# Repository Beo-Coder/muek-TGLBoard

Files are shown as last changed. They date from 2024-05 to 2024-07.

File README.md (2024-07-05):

# TGL Board

### 8x16 ARGB LED Board

This project is a small low profile PCB LED matrix that can be used as a name tag
or to display various text and animations and to play games.

If you have your own "programmable" version,
you can read more about programming [here](#programming)

# About
This project was initially planned as a gift for teachers after our graduation.  
It is a small and low cost LED matrix board.  
It consists of a 8x16 ARGB LED matrix, two buttons as user input and a USB-C jack for powering and programming. 
On the front and backside there are several places where custom text can be written to,
to further individualize the board.  
One of the main goals was that the whole board is visually appealing
and can be used without an enclosure to have a simpler and sleeker looking product.

The electronics consist of an RP2040 microcontroller and a 2 MB (16 Mbit) flash IC.  
You can read more about the electronic [here](#hardware)

To program the board,
you can use SWD on the Tag-Connect connector on the backside as well as on the [custom pads on the backside](#swd-interface).  
It is also possible to program the board over USB-C,
but this needs further hardware modifications (Read more about [here](#usb-c))

# Software
Currently, the software has four modes:

- Displaying text
- Showing animations
- Playing a game
- Setting the brightness

Between these modes, you can easily switch by holding down both buttons at the same time and waiting a bit.
You can choose the mode by going left or right and select it by either waiting or pressing both buttons again.

Inside the different modes, the two buttons have different meanings.
They change the text, the color of the text, the animation, or you can play the game.

## Text
The text can be individually programmed by modifying the [board_text_config.h](src/DisplayText/board_text_config.h) file.

## Animations
There are currently seven different animations:

- Fireworks
- Snake "AI"
- Conway's Game of Life
- Meteorite rain
- Smooth rainbow
- 'Hard' rainbow
- Jumping 'thing'

## Games
There are also two games, but only one is selected by default.

- Dino Game (Default)
- Tetris

To change the game, you need to modify [main.cpp](src/main.cpp).

### Controls: 
#### Dino Game: 
**Left**: *Duck*  
**Right**: *Jump*

After each game, your score and your high score is shown.

#### Tetris:
**Left**: *Moves block to the left*  
**Right**: *Moves block to the right*  
**Right while holding left**: *Rotating block*

After each game, your score and your high score is shown.  
This Tetris game was created by @StarMiner99

## Brightness control
The brightness is only saved when you switch the menu after setting the desired brightness.

# Programming
You can either use PlatformIO (Arduino Framework) or the official C/C++ SDK from Raspberry Pi.  
If you want to use the C/C++ SDK, please use the c-SDK branch.

For details on how these two differ, read [Runtime](README_runtime.md).

## Usage

You need PlatformIO to use this project.  
Arduino IDE might work too (not tested).

In the platform.ini file, there are now two build environments.
`pico_normal` and `pico_fast` you can read about the differences here [Runtime](README_runtime.md).  

For your own programming, you can use my pioMatrixOutput library.
Documentation is here [pioMatrixOutput](READMEpioMatrixOutput.md).

For your own text, you can use my library.
Documentation is here [Textcontroller](README_textController.md).

For flash usage, read here [Flash](README_flash.md).

**Important:**
If you brick your board (can't upload anything) please read [here](README_bricked.md).  

# Hardware

Schematic, layout, BOM and gerber files can be found [here](hardware).  

Each button has a 10k-ohm pull-down resistor and a 100-nF capacitor for debouncing.  

The design of the MCU section follows more or less the [hardware design guide for the RP2040](https://datasheets.raspberrypi.com/rp2040/hardware-design-with-rp2040.pdf).

Because of the design,
it was not possible to add a 100-nF capacitor to each LED, but each row of LEDs (16 each) has its own 10-uF cap
(I know it is not perfect or a replacement).  
Also,
there are multiple more capacitors to further decouple the matrix as good as possible
so that fast-changing patterns do not affect the MCU and its operations.  
This is further improved by the fact the whole MCU subsystem runs on 3.3V over a LDO and not the 5.0V that the LEDs run on. 
While testing, I haven't had any issues with noisy power lines.  
Also, when measuring with my oscilloscope and the matrix turning fully on and fully off as fast as possible, 
I couldn't measure any serious noise on the 5.0V rail nor on the 3.3V rail for the MCU.

## USB-C
Behind the USB-C jack, there are two unpopulated pads.
These pads cut the USB data signal, so that you can't program the board over USB.  
This can be useful, for example,
if you do not want that your teachers get confused when they plug it in to their pc :^)  
If you want to enable USB programming,
you need to short these two pads either with an 0402 0-ohm resistor or simply with solder bridges.  
Be aware that this is quite challenging to solder, you shouldn't destroy/desolder neighboring components.  
Maybe it is easier if you use a hotplate and 0-ohm resistors (Haven't tried it).  
If you order new boards, you can add those to be assembled too.  
The 27-ohm resistors on each USB data line necessary for the RP2040 are already assembled.

It should look something like this:
usb connections usbConnections

## SWD interface
The three unnamed pads on the backside above the UART pads are connections for SWD programming. 

Pinout:
<pre>
board outline
 |
 |          +---+            +---+           +---+
 |         /     \          /     \         /     \
 |        /       \        /       \       /       \
 |       +   RUN   +      +   SWD   +     +  SWCLK  +
 |        \       /        \       /       \       /
 |         \     /          \     /         \     /
 |          +---+            +---+           +---+
 |
 |                  +---+            +---+          
 |                 /     \          /     \ 
 |                /       \        /       \
 |               +   Tx    +      +   Rx    +
 |                \       /        \       /       
 |                 \     /          \     /   
 |                  +---+            +---+
</pre>

# Stand
I also created a stand for the board.
It has three different angles: 90°, 70° and 60°.  
It has place for a name on the top side and for text on the bottom side.  
Inside the stand there are three slots for 1 cent coins (EU) to make the stand more stable.  
If you want to insert those coins, you need to stop the print mid-way and insert/glue the coins in place.  
3mf and STL files can be found [here](hardware/Stand)

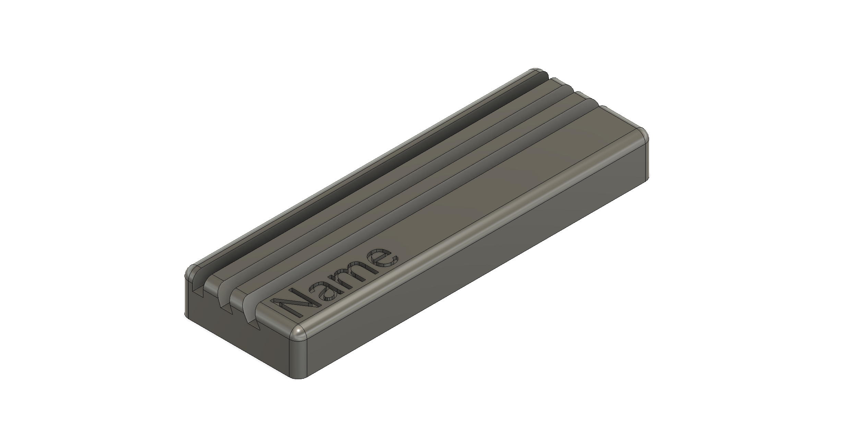
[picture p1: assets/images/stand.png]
stand


If you have any questions, please contact me.

© 2024 Leonhard Baschang

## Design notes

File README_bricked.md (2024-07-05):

If you bricked your board,
and/or you can't upload code anymore,
use a 1k ohm resistor and put it between ground (e.g. USB-C housing)
and the left side of the small smd-resistor above the flash. (See the pictures)  
While holding the resistor, plug the board back into your pc/power and the board should appear as a normal USB-stick.  
Now you can program the board again normally.  

**Be aware that if you place the resistor wrong, you could damage the board!**

This can happen, if your code does stuff that it shouldn't do like to access an array beyond its boundaries.  
Now with watchdog support, it is also possible that the watchdog somehow does not allwo you to program the board.
If you encounter some sort of watchdog related problems, you can simply disable it.

resistor placement resistorPlacement
resistor placement close resistorPlacementClose

© 2024 Leonhard Baschang

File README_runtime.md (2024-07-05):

# Runtime

## Intro
There are four different build environments:
- PlatformIO Normal
- PlatformIO Fast
- C/C++ SDK (Debug)
- C/C++ SDK (Release)

On an execution speed perspective, the C/C++ SDK release is by far the fastest.  
The fast PlatformIO environment comes seconds but is still significantly slower than the C/C++ SDK.  
The normal PlatformIO environment comes in third with sometimes near or worse performance to the fast PlatformIO environment.
The C/C++ SDK debug environment is last.

Here is a table of some measurements in the different environments

| Operation | PlatformIO Normal | PlatformIO Fast | C/C++ SDK Debug | C/C++ SDK Release |
|---|---|---|---|---|
| Creation of 1000 hamiltonian cycles | 5.472.567 | 5.313.235 | 6.995.862 | 3.246.311 |
| Calculation of 1000 Game of Life frames<br/>(without loading or displaying) | 376.821 | 368.443 | 511.537 | 149.013 |
| Calculation of 1000 Firework frames<br/>(without loading or displaying) | 920.234 | 444.682 | 431.344 | 364.977 |

All measurements are in µs.  
Note that the measurements are not 100% precise and are sometimes dependent on randomness.
But they still give a good idea of the different runtimes.

The differences can be tracked down two a few things.
The C/C++ SDK is way more optimized for the RP2040 than the Arduino (PlatformIO) framework is.
This is especially true to floating point
and divide operations
because the Arduino framework does not normally use the build in software/hardware features that the RP2040 has.  
In the PlatformIO fast environment, I added some of these features (floating point computation and hardware divider).

## Floating point computation

### Intro
The RP2040 does not have a floating-point-point(FPU), so the hardware does not support floating-point numbers.
But with a little bit of math magic, you can still calculate with floating-point numbers.
But this math magic is relatively slow and thus is not as performant as "normal" fixed-point numbers.

This math magic is "normally" done by the compiler and is done in a way so that all CPUs without an FPU can calculate this.
But luckily, Raspberry Pi developed their own piece of software which has a drastically better performance than the "normal" compiler math magic.

This piece of code is not normally used by the Arduino Framework for the RP2040.
So we need to include it ourselves.

This is why there are now two different build environments.  
`pico_normal` uses the normal algorithms from the compiler.  
`pico_fast` uses the algorithms specialized for the RP2040.  

Code wise in C/C++ there are no changes.

Note that `pico_fast` is not well tested and can crash or behave "weird".

To learn more and read about the performance increases,
see the documentation of the [C/C++ SDK section 2.7](https://datasheets.raspberrypi.com/pico/raspberry-pi-pico-c-sdk.pdf#sdk-runtime-section).

And yes, "math magic" is a real word! :^)

© 2024 Leonhard Baschang

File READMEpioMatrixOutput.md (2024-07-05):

# PIO Matrix Output Library

### Library to interface with the 8x16 ARGB Display

# Table of Contents
1. [Features](#features)
2. [Overview](#overview)
   1. [Modes](#modes)
   2. [Terminology](#terminology)
3. [Usage](#usage)
4. [Explanations](#explanations)
   1. [Framebuffer](#framebuffer)
   2. [Frame bs Subframe](#frame-vs-subframe)
   3. [RAM Usage](#ram-usage)
   4. [Output](#output)
5. [Notes](#notes)

# Features

- Framebuffer support
- Subframes support
- No CPU interaction needed during output
- Two (real) parallel outputs
- Fast refresh rate possible (~200 Hz)

# Overview
## Modes
There are two main modes of usage:
- Manual mode
- Automatic (framebuffer) mode

In Manual mode, you are responsible for creating the frames, sending the frames to the library and telling the software when to display the frames.

In Automatic (framebuffer) mode, you are only responsible for creating and sending the frames to the software.
The software will then display the frames on a fixed clock/time.
In this mode, frames are stored, as the name framebuffer implies.

## Terminology
**Frame:**
A frame is one image on the display.

**Subframes:**
One frame can be divided in subframes.
Subframes are used to create a larger range of colors and gradations.

To learn more about frames and subframes, please read [frame vs subframe](#frame-vs-subframe)

# Usage
## General use
### Initialize
`MatrixOutput ledMatrix(<pio>, <sm>, <dmaChannel>, <pin1>, <pin2>);`
- **ledMatrix**: name of the object
- **pio**: Identifier for the PIO instance (e.g. `pio0` (see examples))
- **sm**: Index of the state machine inside the PIO (e.g. `0`)
- **dmaChannel**: Index of the dma channel to use (e.g. `0`)
- **pin1**: GPIO pin of the first matrix half (e.g. `10`)
- **pin2**: GPIO pin of the second matrix half (e.g. `11`)

<br/>

### Enable Subframes
`ledMatrix.enableSubframes(<enable>);`

- **enable**: `true` or `false`. By default `true`

This command enables/disables subframes.

<br/>

### Clear Display
`ledMatrix.clearDisplay();`

Clears the display, disables subframes and the framebuffer.

<br/>

## Manual mode
### Setting display data
`ledMatrix.setDisplayData(<data>);`

- **data**: Address of an 8 by 16 Color array (see examples)

This command only sets the next frame to be sent. It does not send the data.

<br/>

### Displaying the data
`ledMatrix.sendData();`

Send the data to the display.

<br/>

## Automatic mode
### Enable Framebuffer
`ledMatrix.enableFramebuffer(<enable>);`

- **enable**: `true` or `false`. By default `true`

This command enables/disables the framebuffer.

<br/>

### Set Framebuffer interval
`ledMatrix.setFrameBufferInterval(<interval>);`

- **interval**: time in ms until the next frame is displayed (e.g. `90`)

If set to `0` the framebuffer remains on, but the timer is disabled.
You need to send the data manually.  
The interval can be set any time.

<br/>

### Load frame to framebuffer
`ledMatrix.addToFrameBuffer(<data>);`

- **data**: Address of an 8 by 16 Color array (see examples)

This command only loads the next frame to be s. It does not send the data.

<br/>

### Get free frames
`uint8_t freeFrames = ledMatrix.getFreeFrames();`

Returns the number of frames that can be added to the framebuffer before it overflows.

# Explanations
## Framebuffer
As the name suggests it buffers frames.   
Normally it is set to store up to 10 frames.
These frames can be pre-rendered by the CPU and then get output on a fixed timing/clock signal.

## Frame vs Subframe
The LEDs used in the Matrix are ARGB LEDs.
That means that each LED will remember its color.
This means that for one frame we only need to send one data frame to each LED.
So 128 dataframes in total for the whole matrix.   
So the CPU can spin around in circles until the next frame has to be sent.

Instead of waiting and spinning around (even if this is fun), the CPU could use this time to output more and more frames over and over again.  
For example, in the time the CPU waits for the next frame, there could be sent three more frames.   
And this is exactly what subframes are.  
One frame is divided in different subframe (four subframes by default).
By using the subframes in a smart way, we can create more shades of a color.
It is like PWM but fancy and more complex (not really but hey).

So if we only have frames we could only display distinct values of brightness (0,1,2, ...)
For example, we would send a `1` once to have a brightness level of 1.

But with subframes, we also can display 0.5 as a brightness level.
As described, we divide one frame into, for example, four subframes.
To display 0.5 as a continuous brightness level, we would send
`1100, 1100, 1100, 1100, ...`
over and over again. 
In this way, we can create smaller steps in brightness.
With 4 subframes, we can go in steps of 0.25.

This is, of course, a simple example, but this is what the software is doing if you enable subframes.  
You cannot directly control the values of the subframes.
Subframes are calculated and stored when setting the frame either as data or when adding the frame to the framebuffer.

## RAM usage
As you can imagine, subframes in combination with the framebuffer are really RAM intensiv.
And yes, that is true.  
Normally, we can store 10 frames in the frame buffer.
Each of these frames has four subframes.
And each subframe needs to store the color information for each of the 128 LEDs.
Each LED takes three bytes of data.  
3 x 128 = 384 bytes per subframe.  
384 x 4 = 1536 bytes per frame.  
1536 x 10 = 15360 bytes.  
That is a lot of memory.  
Especially if you remember that an Arduino UNO (R3) only has 2kB of RAM.
We use more than 7 times the amount just for the framebuffer alone.  
In total, the RP2040 has 256 kBytes of RAM.
So we have plenty to spare. (Maybe more subframes?...)

## Output
The cool thing about the RP2040 is that it has PIO.  
PIO stands for programmable IO.  
To break it down. 
It has 2 PIO Blocks with 4 State Machines each.
Each of these state machines is like a really, really, really tiny CPU.
Each machine has one input and one output buffer to get data to and from the machine.
This data can be output to the GPIO pins.
Inside these machines you can programm a small programm, to output the data just as you want.
And the output is parallel on as many pins as you want.  
To learn more about PIO,
read the [documentation of the RP2040 Chapter 3](https://datasheets.raspberrypi.com/rp2040/rp2040-datasheet.pdf#section_pio).

These state machines run independently of the CPU. 
The CPU only needs to set up the machine and handel the data in the input/output registers.

This alone is already really cool.
But it gets even better.

Even if the CPU only needs to handle the loading of the state machine register, this is still a lot of time wasted on simple tasks.   
There is a cool feature in many microcontrollers called DMA.   
DMA stands for direct memory access. 
The DMA can access memory and copy data from one place to another. 
And this extremely fast and without interaction of the CPU.
So we have an array of data in the RAM.
This data has been rendered by the CPU and stored in the RAM.
The DMA takes this data and loads it in small pieces into the state machine buffer which then outputs it onto the GPIO pins.
And all this without any interaction from the CPU.  
While the DMA and the PIO are output the data and loading the LEDs with data, the CPU can already render the next frame and/or spinning around in circles :)

# Notes
When using subframes and/or the framebuffer, please don't use the `delay` instruction.
It can mess up everything.

© 2024 Leonhard Baschang

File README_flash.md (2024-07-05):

# Flash usage
## Intro
The RP2040 does not have an internal flash.
All the flash is outside in the small black ic package on the left side over the RP2040.  
The CPUs can directly interface with this memory and execute code from it (XIP).  
The pico has some functions that let us write to this flash during runtime.  

## Usage
### Initialize
`FlashController flash;`

<br/>

### Read data
`uint8_t* data = flash.readData(<accessKey>);`

- **accessKey**: Key/ID for the data you want to access
- **data**: Start address of the data.

<br/>

### Write data
`bool status = flash.writeData(<accessKey>,<data>);`

- **accessKey**: Key/ID for the data you want to access
- **data**: The beginning of an array, where the data is stored you want to write.
- **status**: `true` if successful.

Please do not call this function unnecessary often.
Please check first if the data has changed before writing.

<br/>

### Erase all data
`flash.eraseAllData();`

This command erases all data currently stored in flash (only the data which we can also write (no code))  
Only use this when you exactly know what you are doing.  
Theoretically, you should never use this function if you use this library correctly (and it has no bugs...)

<br/>

### Add a new access key
To read or write data, the flash controller needs to know where your data is stored and how big it is.
This is achieved through predefined datasets (FlashItem).  
Each dataset has an accessKey (ID) and a size (number of bytes).  
To add/remove these, you must modify flash_controller.h/.cpp.  
**Note**: An access Key must be unique.
All the number of bytes combined should not be more than 256-1 (255), or you have to increase NUMBER_OF_PAGES by 1.  
No flash item should have more than 255 bytes of size.  
No flash item should overlap between pages (you can fill space with dummy content).

## Notes
During writing and erasing, there are no IRQs allowed, and only one core is allowed to access the flash.
The IRQs are handled by the flash controller itself.
It will disable the IRQs at the beginning of a flash command and restore them at the end.  
That only one core is running is your responsibility!  
We can only store 4095 bytes of data (one sector - internal byte)

Also see flash example.

## Technical notes
Flash can only be written to in 256 byte pages.  
Flash can only be erased in 4096 byte sectors.  
Erasing a sectors sets all bits to `1`.  
Writing only sets bits to `0`.  
So you cant write on the same address multiple times or data will get lost because you can't write an `1`.  
Because every erase-cycle wears out the flash, we only erase the sector if all the pages inside have been written.  
To further protect the flash from too many erase-cycles, we use multiple flash sectors to write our data and increment every time to the next sector.  
If no empty pages are found, we erase.  
This controller currently uses five sectors of flash.
This is a size of 4096*5 (20.480) bytes.  
This gives us 80 (20.480/256) write cycles before we need to erase.  
The flash that is solders to the board has, according to spec, a minimum of 100k erase-cycles per sector.  
This gives us 8.000.000 write cycles.  
Still, you should check if your data has changed and need rewriting before writing it again.

To every page we write, we steal one byte for internal use.  
This is the first byte to each page.  
When writing, we set this byte to a specific pattern.
With this pattern, we can easily detect a full / empty page of data.

To even further decrease erase-cycles, we could divide each page in smaller pieces.  
But this functionality is an idea for the future. :^)   
( ._.)

© 2024 Leonhard Baschang

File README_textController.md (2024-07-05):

# Textcontroller Library

### Library for multiple text controllers to display different kinds of text

# Overview
There are three different kinds of controllers. 
Scroll text, static text and tiny text.  
- **Scroll text**:
  The text is as high as the matrix and scroll from right to left
  (or from left to right) and start at the beginning if it reaches the end. 
  It is basically an endless loop of the same text.
- **Static text**: The text scrolls from right to left, but when it reaches the end it scrolls back to the beginning.
- **Tiny text**: 
  Same as static text, but only on half the size of the matrix. 
  The matrix is split in an upper and lower part.
  Each part can be controlled individual.

# Usage
## General use 
### Initialize
`ScrollText textController(<matrixOutput>, <frame>);`  
`StaticText textController(<matrixOutput>, <frame>);`  
`TinyText textController(<matrixOutput>, <frame>);`
- **matrixOutput**: Address of the MatrixOutput object (see example)
- **frame**: Address of the Color frame\[8\]\[16\] object (see example)

<br/>

### Set colors (only scroll and static text)
`textController.setColor(<textColor>, <backgroundColor>);`

- **textColor**: Address of the color for the text.
- **backgroundColor**: Address of the color for the background.

<br/>

### Set colors (only tiny text)
`textController.setColor(<upperTextColor>, <lowerTextColor>, <backgroundColor>);`

- **upperTextColor**: Address of the color for the text in the upper half.
- **lowerTextColor**: Address of the color for the text in the lower half.
- **backgroundColor**: Address of the color for the background

<br/>

### Set text (All controllers)
`textController.setText(<text>);`

- **text**: Address of the text stored as `std::string`.

<br/>

### Set text individual (tiny text only)
`textController.setUpperText(<text>);`  
`textController.setLowerText(<text>);`

- **text**: Address of the text stored as `std::string`.  
Sets the text individual for the upper/lower half.

See [decoding table](#decoding-table)

<br/>

### Refresh (shift + send to matrix) (All controllers)
`textController.refresh();`

This command shifts the text one place and displays it to the matrix.
Or display the static text.

<br/>

### Create and Load frame (shift + load frame) (All controllers)
`textController.createAndLoadFrame();`

This command creates the frame and loads it in to the buffer, so that it can be send as the next frame.  
You need to send the frame manually
(`matrix.sendData()`).

<br/>

### Set left/right shift (only scroll text)
`textController.setMode(<leftShift>);`

- **leftShift**: `bool`.
  If `true` text is shifted from right to left. 
  If `false` from left to right.
  Default is `true`

<br/>

# Decoding Table

`String text = "Hello World %H";`

(input -> output(on display))

## Normal Font (scroll and static text)
### Normal letters
`A` -> `A`  
`B` -> `B`  
...  
`y` -> `y`  
`z` -> `z`  

`0` -> `0`  
...  
`9` -> `9`

*space* -> *space* (5 pixel)    

`(` -> `(`  
`)` -> `)`  
`[` -> `[`  
`]` -> `]`  
`{` -> `{`  
`}` -> `}`  
`<` -> `<`  
`>` -> `>`

`.` -> `.`  
`,` -> `,`  
`_` -> `_`  
`-` -> `-`  

`?` -> `?`  
`!` -> `!`  
`:` -> `:`  
`;` -> `;`

### Special character (with `%` in front (`%A` -> `Ä`))

`A` -> `Ä`  
`a` -> `ä`  
...  
`ü` -> `ü`  

`1` -> *space* (1 pixel)  
`2` -> *space* (2 pixel)  
`3` -> *space* (3 pixel)  
`4` -> *space* (4 pixel)  

`l` -> *vertical line* (1 pixel)  
`|` -> *vertical line* (1 pixel) (same as l)  

`(` -> `(` (another design)  
`)` -> `)` (another design)  

`H` -> *Heart symbol*  
`S` -> *Smiley face*  

<br/>

## Tiny Font (tiny text)
### Normal letters
`A` -> `A`  
`B` -> `B`  
...  
`y` -> `A`  
`z` -> `Z`

There is no difference between small and capital letters.

`0` -> `0`  
...  
`9` -> `9`

*space* -> *space* (3 pixel)

`(` -> `(`  
`)` -> `)`  
`[` -> `[`  
`]` -> `]`   

`.` -> `.`  
`,` -> `,`  
`_` -> `_`  
`-` -> `-`

`?` -> `?`  
`!` -> `!`  
`:` -> `:`  
`;` -> `;`

`/` -> `/`  
`\ ` -> `\ `

### Special character (with `%` in front)

`1` -> *space* (1 pixel)  
`2` -> *space* (2 pixel)

`l` -> *vertical line* (1 pixel)  
`|` -> *vertical line* (1 pixel) (same as l)

`n` -> special char to indicate the line break if `text.setText(<text>);` is used.  
For example:
`Hello%nWorld` would become  
`Hello` (upper half)  
`World` (lower half)  

© 2024 Leonhard Baschang

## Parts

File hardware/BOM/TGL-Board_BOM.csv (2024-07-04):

Reference | Value | Footprint | LCSC
C1,C2,C5,C6,C7,C8,C9,C10,C11,C14,C16,C20,C21 | 100n | Capacitor_SMD:C_0402_1005Metric | C1525
C3,C4 | 1u | Capacitor_SMD:C_0402_1005Metric | C52923
C12,C13 | 15p | Capacitor_SMD:C_0402_1005Metric | C1548
C15,C17,C18,C22,C23,C24,C25,C26,C27,C28,C29 | 10u | Capacitor_SMD:C_0603_1608Metric | C19702
C19 | 47u | Capacitor_SMD:C_0805_2012Metric | C16780
D1,D2,D3,D4,D5,D6,D7,D8,D9,D10,D11,D12,D13,D14,D15,D16,D17,D18,D19,D20,D21,D22,D23,D24,D25,D26,D27,D28,D29,D30,D31,D32,D33,D34,D35,D36,D37,D38,D39,D40,D41,D42,D43,D44,D45,D46,D47,D48,D49,D50,D51,D52,D53,D54,D55,D56,D57,D58,D59,D60,D61,D62,D63,D64,D65,D66,D67,D68,D69,D70,D71,D72,D73,D74,D75,D76,D77,D78,D79,D80,D81,D82,D83,D84,D85,D86,D87,D88,D89,D90,D91,D92,D93,D94,D95,D96,D97,D98,D99,D100,D101,D102,D103,D104,D105,D106,D107,D108,D109,D110,D111,D112,D113,D114,D115,D116,D117,D118,D119,D120,D121,D122,D123,D124,D125,D126,D127,D128 | WS2812B | LeosLib:LED_WS2812B_XL-1615RGBC-WS2812B | C5349954
IC1 | W25Q16JVUXIQ_TR | W25Q16JVUXIQ:SON50P300X200X60-9L | C2843335
J2 | USB_C_Receptacle_USB2.0_16P | Connector_USB:USB_C_Receptacle_GCT_USB4105-xx-A_16P_TopMnt_Horizontal | C2858270
R1 | 1k | Resistor_SMD:R_0402_1005Metric | C11702
R2,R6,R7 | 10k | Resistor_SMD:R_0402_1005Metric | C25744
R3,R4 | 5.1k | Resistor_SMD:R_0402_1005Metric | C25905
R5 | 100k | Resistor_SMD:R_0402_1005Metric | C25741
R8,R9 | 27 | Resistor_SMD:R_0402_1005Metric | C25156
S1 | Button 1 | PTS526:PTS526SK15SMTR2LFS | C318884
S2 | Button 2 | PTS526:PTS526SK15SMTR2LFS | C318884
U1 | RP2040 | Package_DFN_QFN:QFN-56-1EP_7x7mm_P0.4mm_EP3.2x3.2mm | C2040
U2 | AP2112K-3.3 | Package_TO_SOT_SMD:SOT-23-5 | C51118
Y1 | ABM8G-12.000MHZ-4Y-T3 | Crystal:Crystal_SMD_3225-4Pin_3.2x2.5mm | C9002

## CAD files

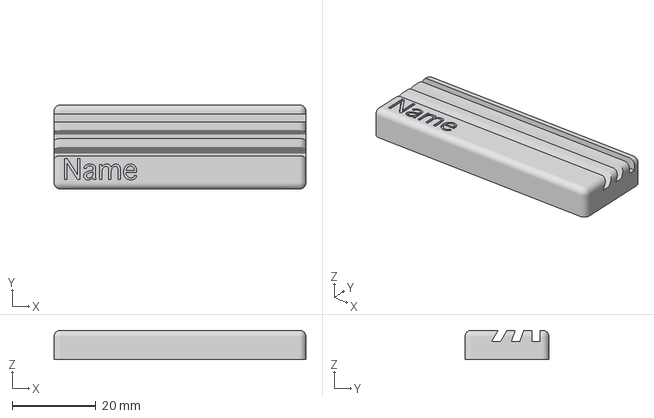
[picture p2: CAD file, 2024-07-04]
hardware/Stand/TGL-Board_Stand.3mf
60.0 x 20.0 x 7.00 mm

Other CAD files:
hardware/Stand/TGL-Board_Stand.stl

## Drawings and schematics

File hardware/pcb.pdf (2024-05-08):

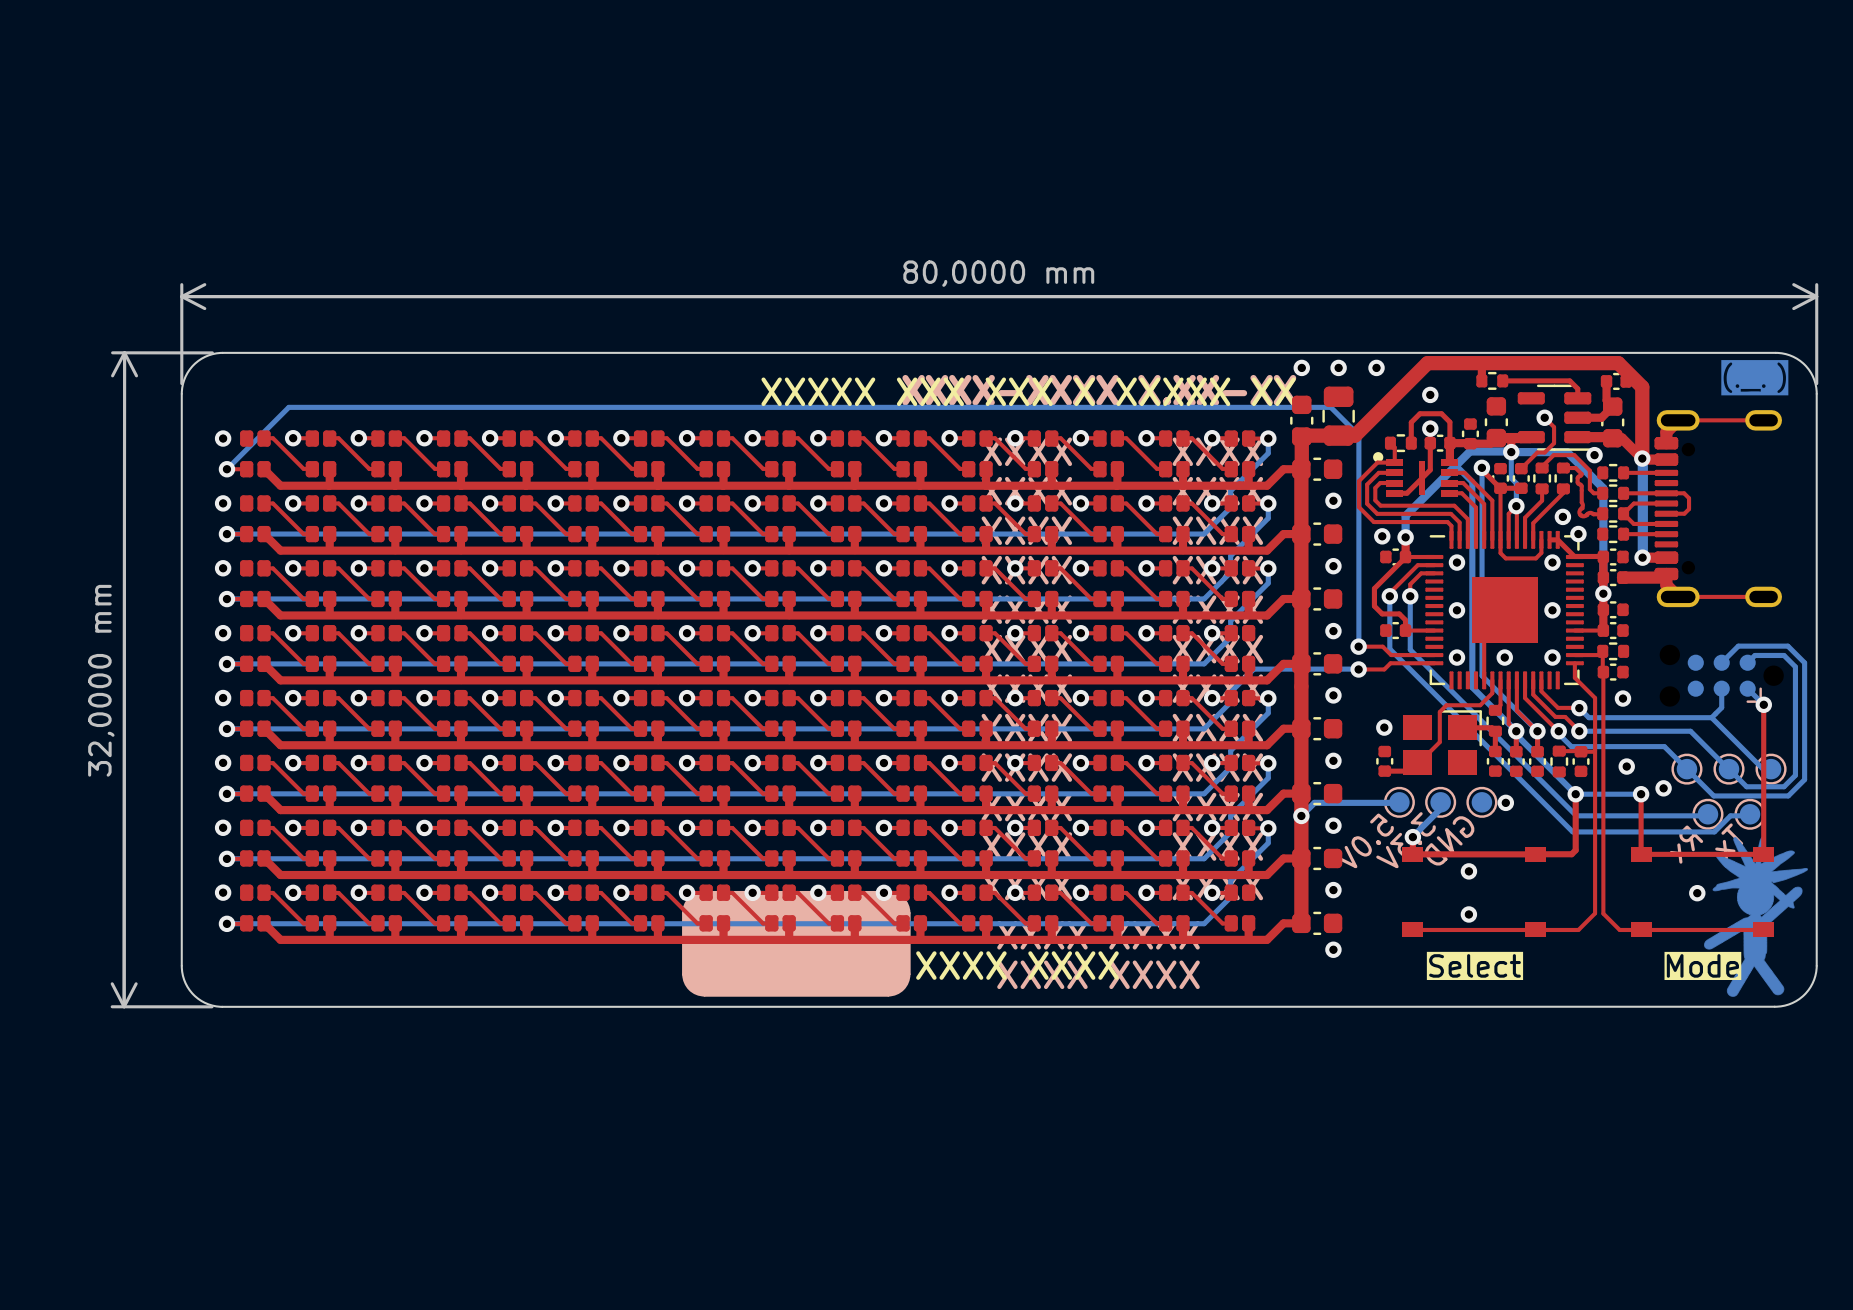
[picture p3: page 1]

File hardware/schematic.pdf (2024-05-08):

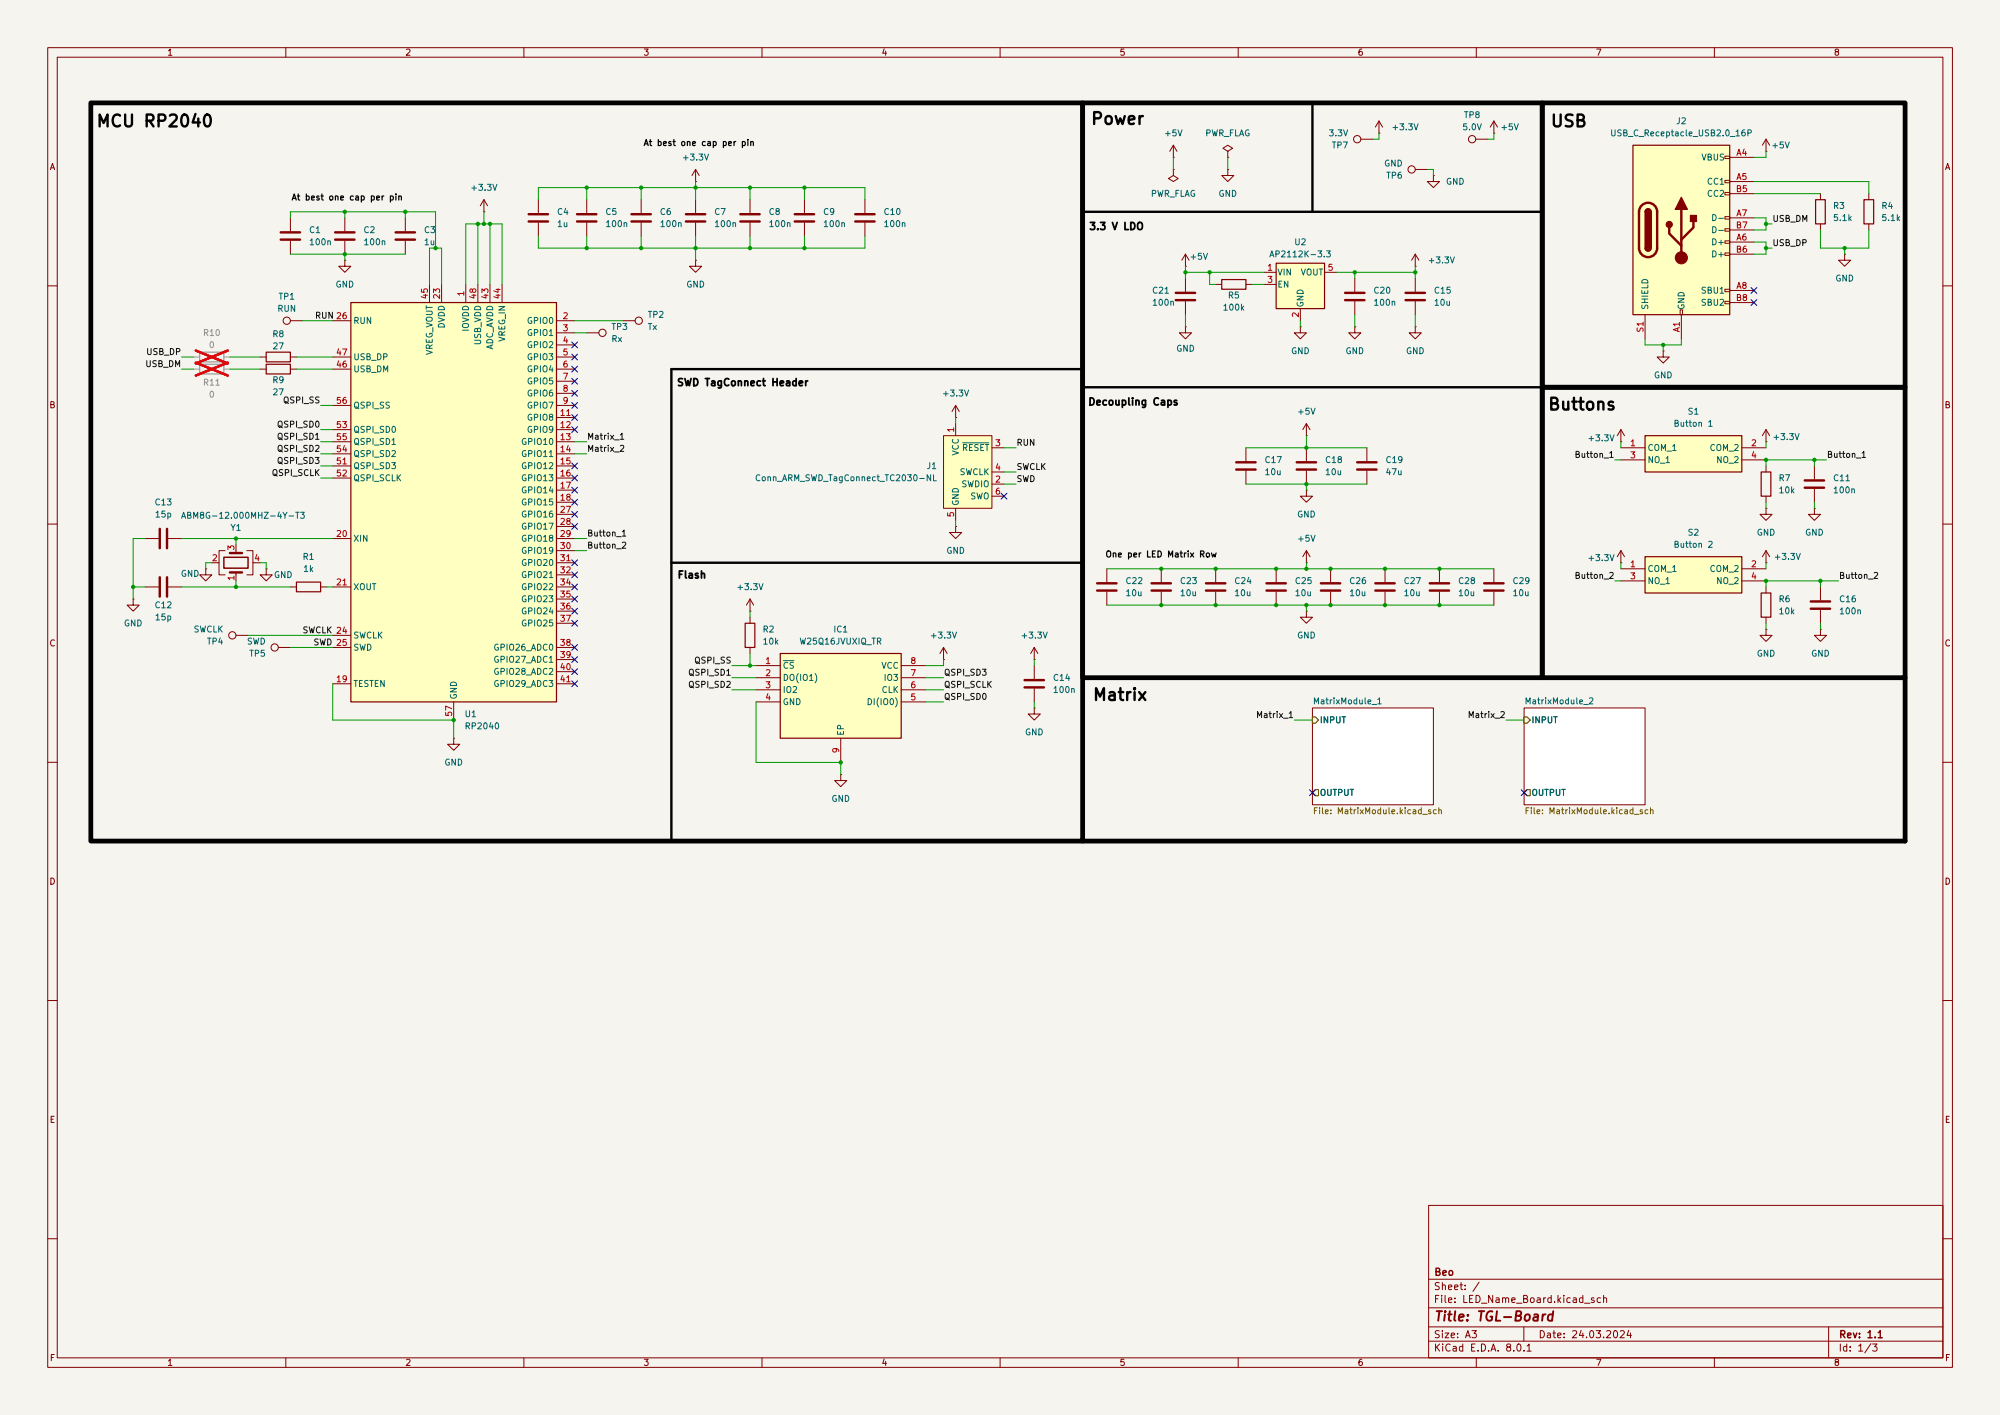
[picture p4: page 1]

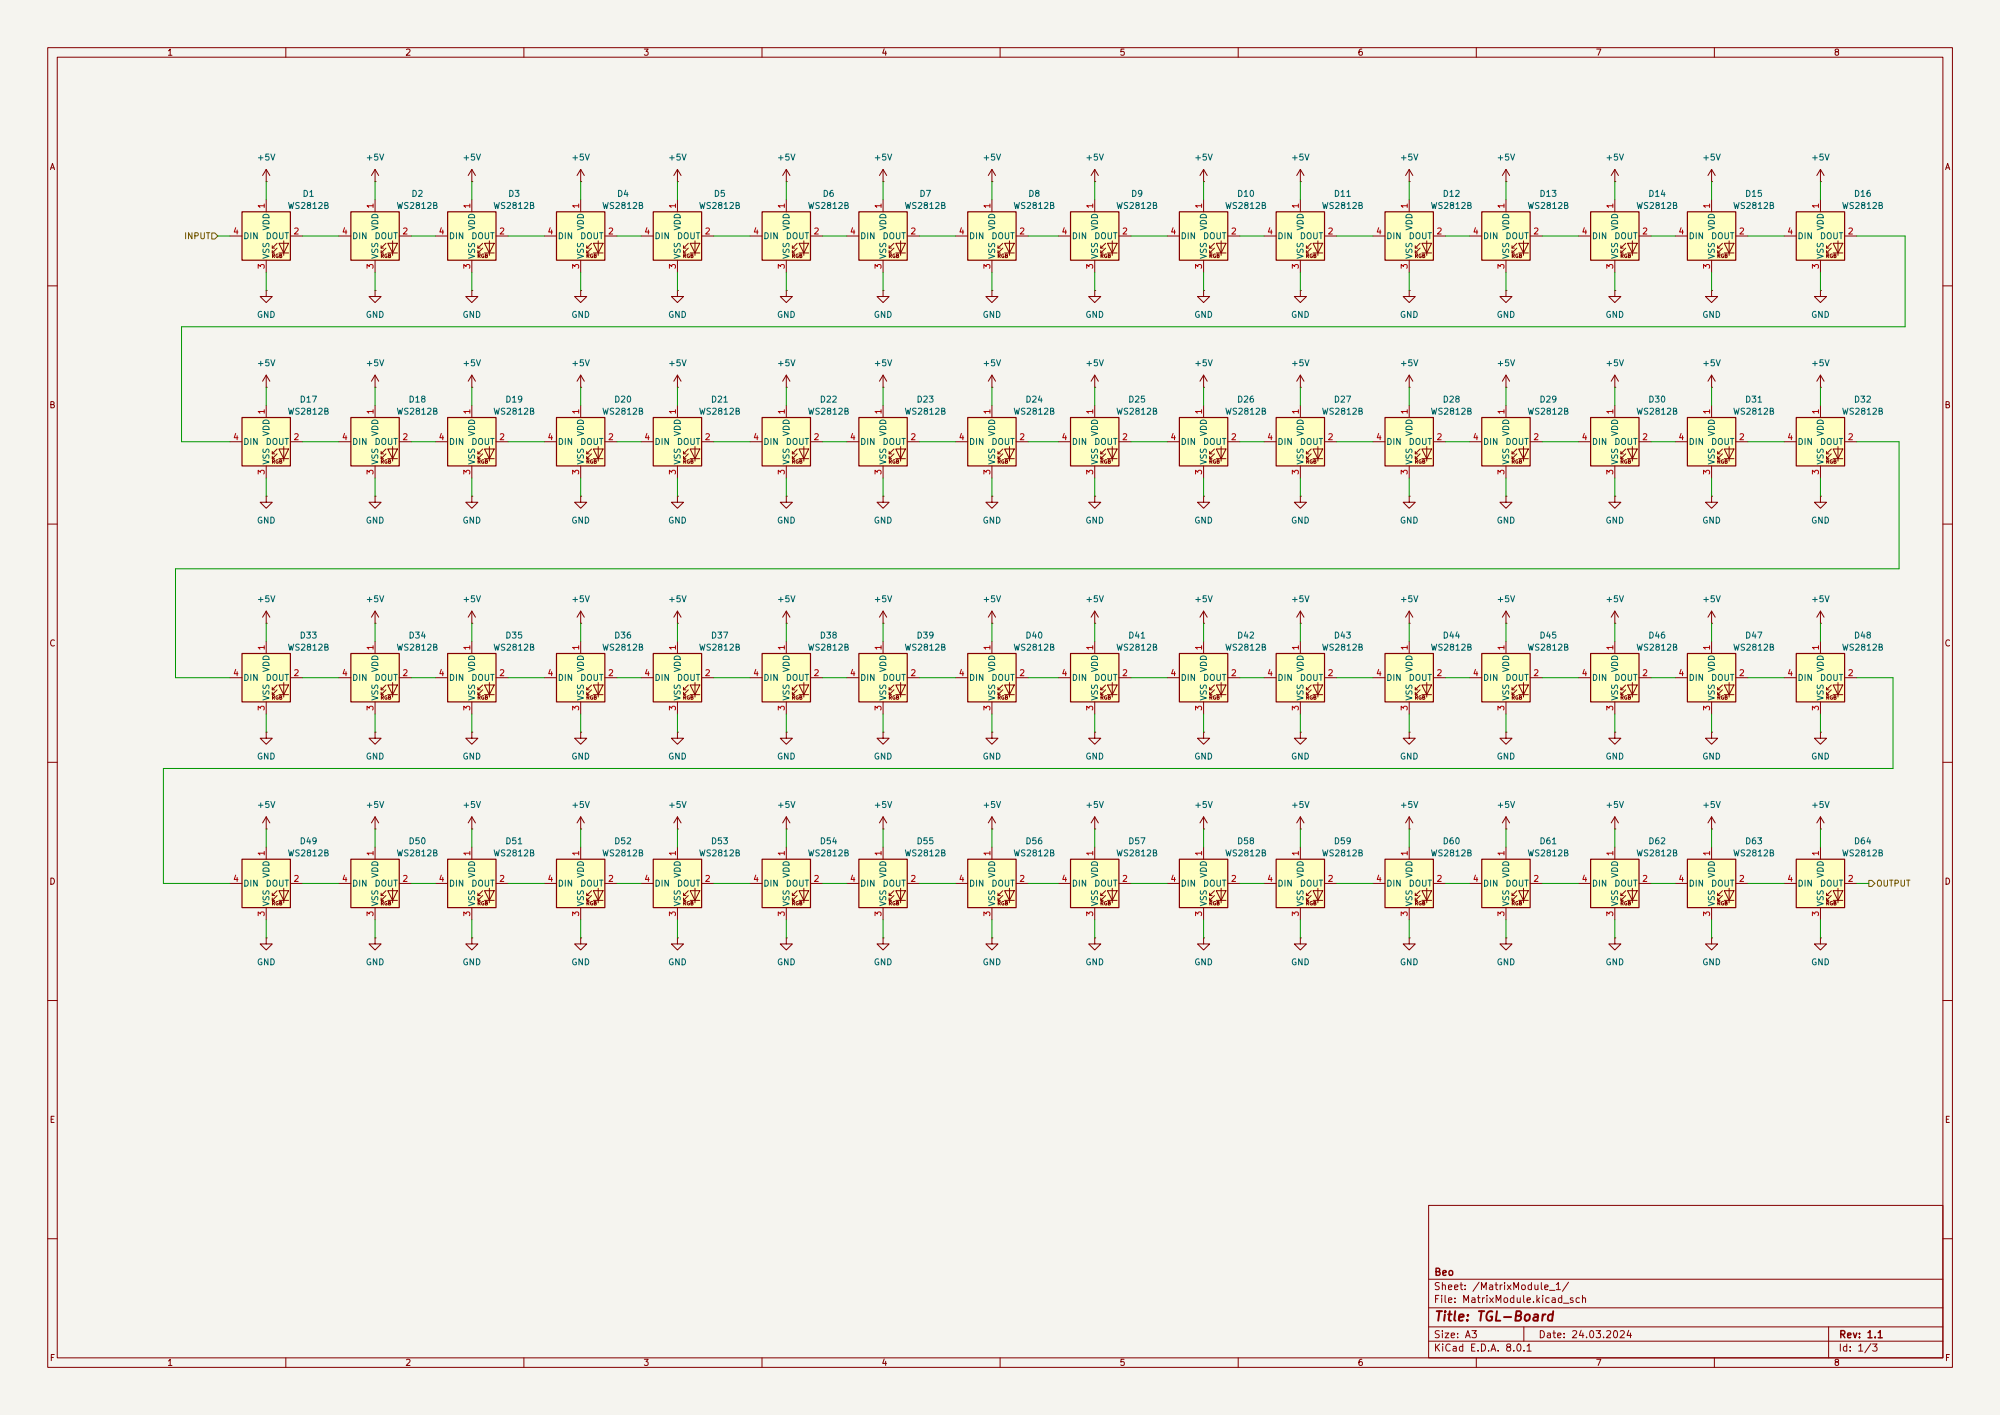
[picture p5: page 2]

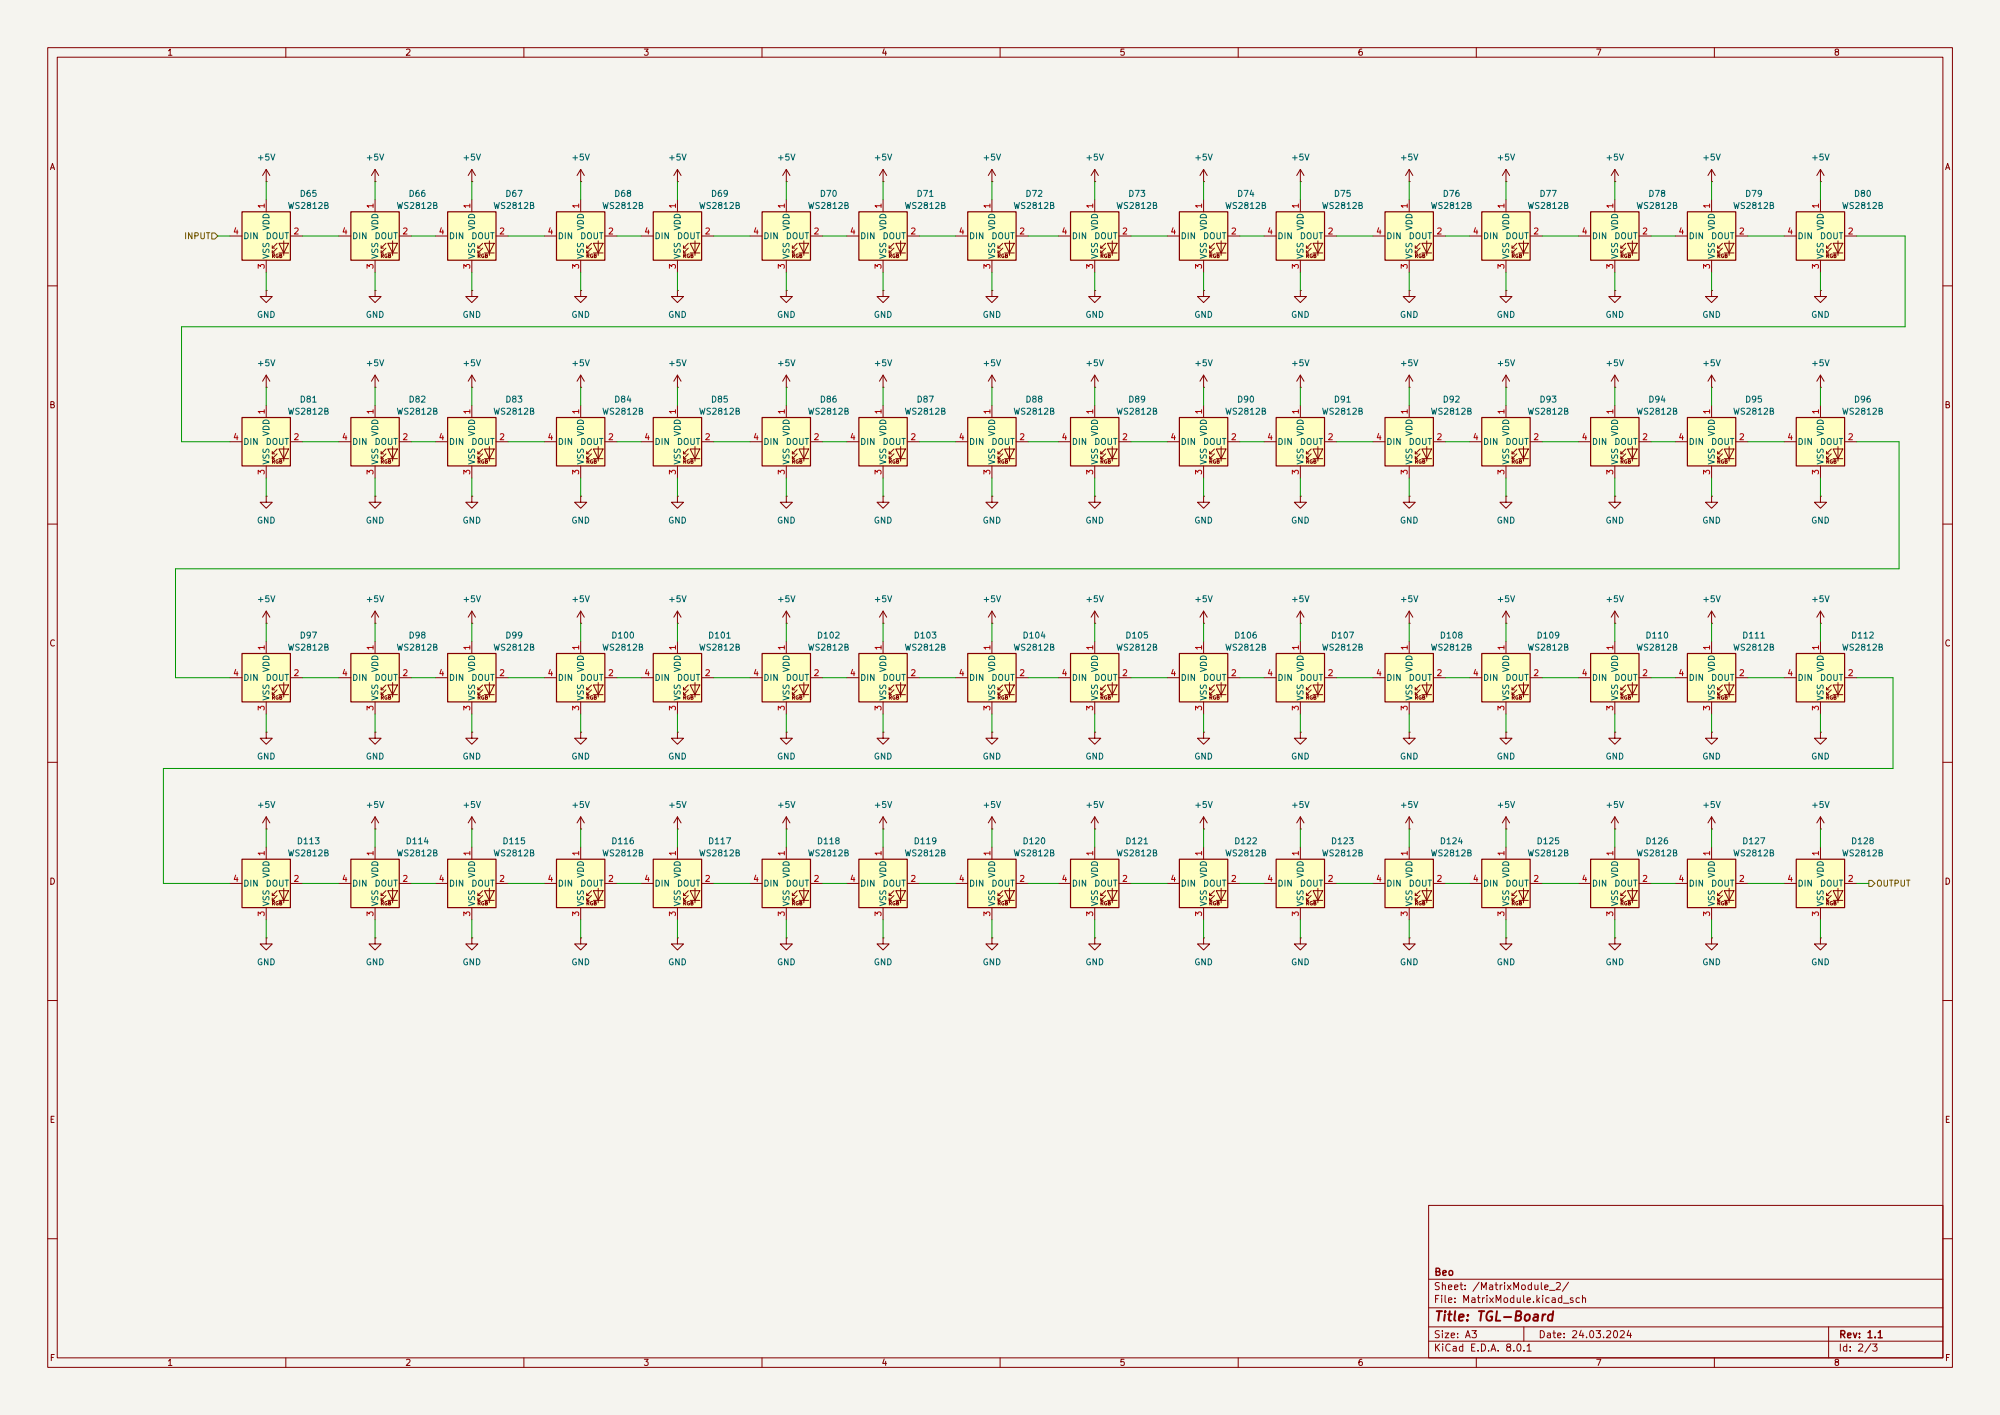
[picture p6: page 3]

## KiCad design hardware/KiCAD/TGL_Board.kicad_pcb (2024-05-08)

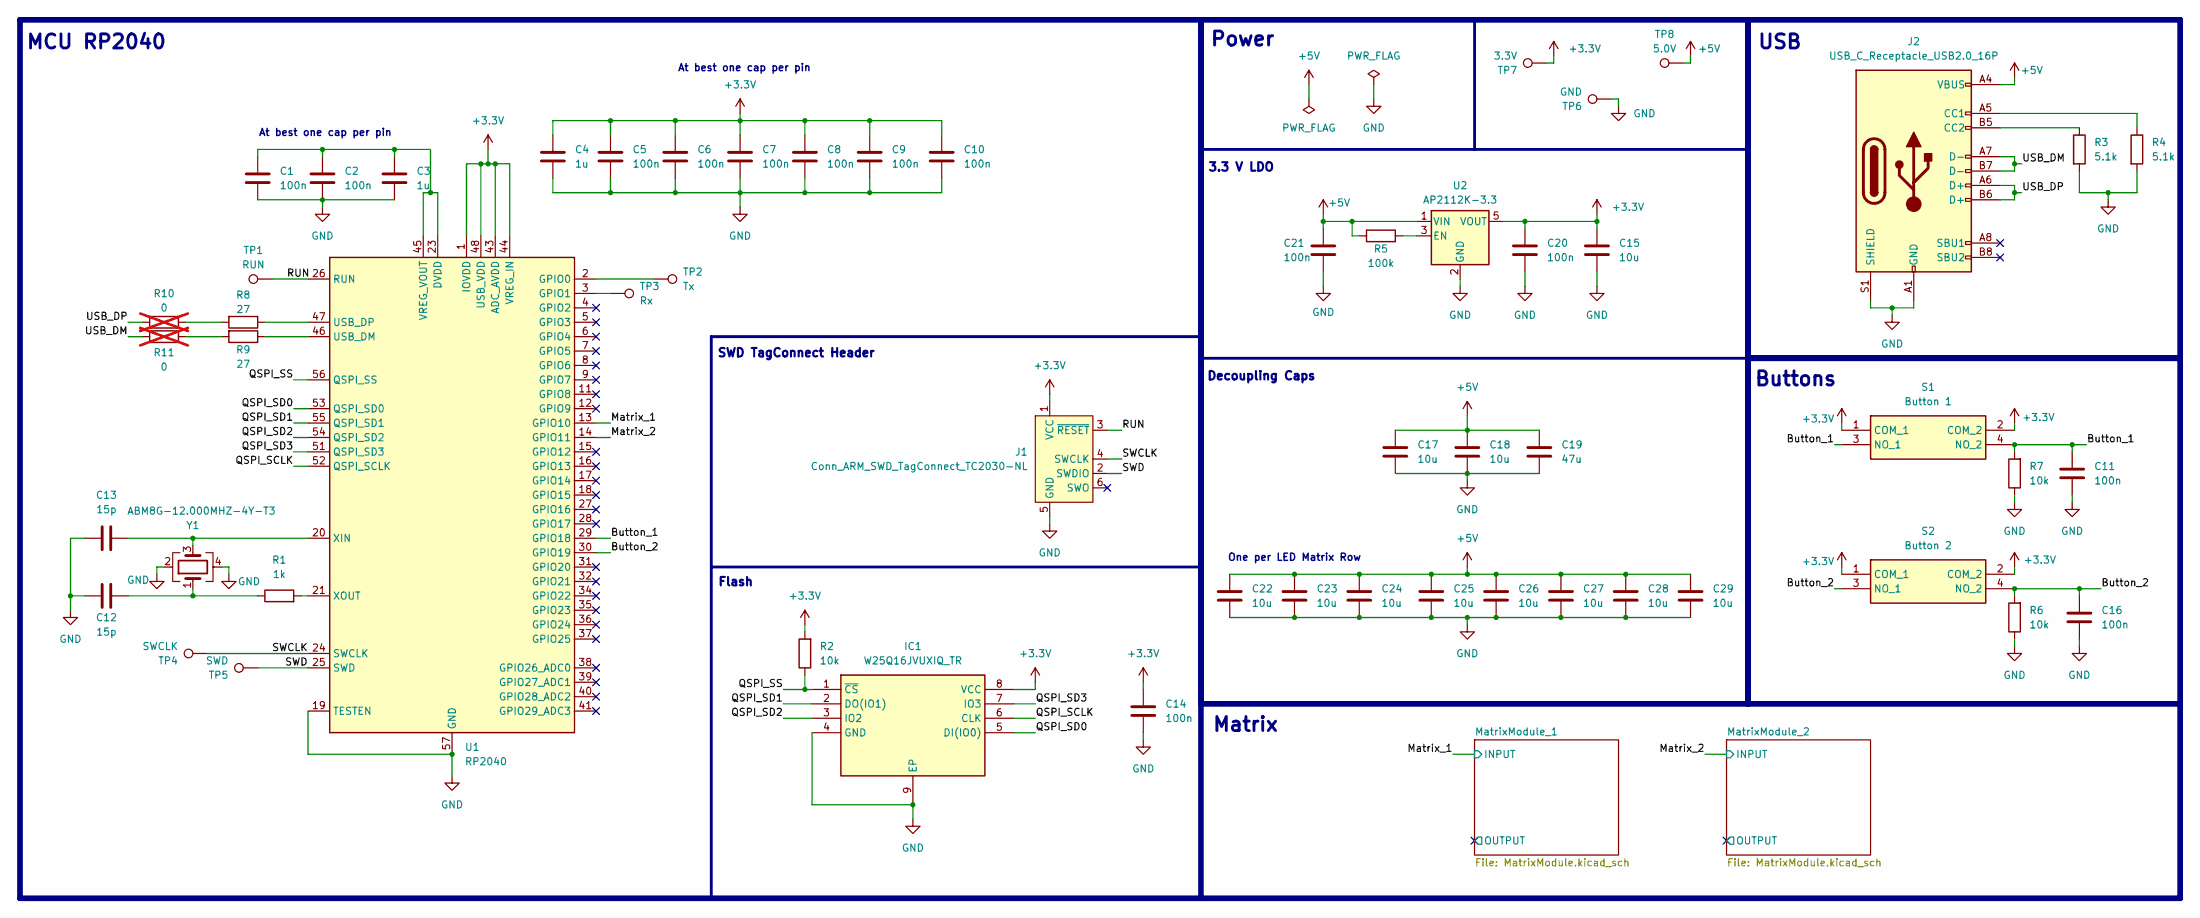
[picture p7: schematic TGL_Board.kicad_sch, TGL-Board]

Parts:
C1, C2, C5, C6, C7, C8, C9, C10, C11, C14, C16, C20, C21: 100n; C_0402_1005Metric; LCSC C1525
C3, C4: 1u; C_0402_1005Metric; LCSC C52923
C12, C13: 15p; C_0402_1005Metric; LCSC C1548
C15, C17, C18, C22, C23, C24, C25, C26, C27, C28, C29: 10u; C_0603_1608Metric; LCSC C19702
C19: 47u; C_0805_2012Metric; LCSC C16780
IC1: W25Q16JVUXIQ_TR; SON50P300X200X60-9L; Mouser Part Number 454-W25Q16JVUXIQTR
J1: Conn_ARM_SWD_TagConnect_TC2030-NL; Tag-Connect_TC2030-IDC-NL_2x03_P1.27mm_Vertical
J2: USB_C_Receptacle_USB2.0_16P; USB_C_Receptacle_GCT_USB4105-xx-A_16P_TopMnt_Horizontal; LCSC C2858270
R1: 1k; R_0402_1005Metric; LCSC C11702
R2, R6, R7: 10k; R_0402_1005Metric; LCSC C25744
R3, R4: 5.1k; R_0402_1005Metric; LCSC C25905
R5: 100k; R_0402_1005Metric; LCSC C25741
R8, R9: 27; R_0402_1005Metric; LCSC C25156
R10, R11: 0; R_0402_1005Metric; not fitted
S1: Button 1; PTS526SK15SMTR2LFS; Mouser Part Number 611-PTS526SK15SMR2L
S2: Button 2; PTS526SK15SMTR2LFS; Mouser Part Number 611-PTS526SK15SMR2L
TP1: RUN; TestPoint_Pad_D1.0mm
TP2: Tx; TestPoint_Pad_D1.0mm
TP3: Rx; TestPoint_Pad_D1.0mm
TP4: SWCLK; TestPoint_Pad_D1.0mm
TP5: SWD; TestPoint_Pad_D1.0mm
TP6: GND; TestPoint_Pad_D1.0mm
TP7: 3.3V; TestPoint_Pad_D1.0mm
TP8: 5.0V; TestPoint_Pad_D1.0mm
U1: RP2040; QFN-56-1EP_7x7mm_P0.4mm_EP3.2x3.2mm; LCSC C2040
U2: AP2112K-3.3; SOT-23-5; LCSC C51118
Y1: ABM8G-12.000MHZ-4Y-T3; Crystal_SMD_3225-4Pin_3.2x2.5mm; LCSC C9002

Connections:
+3.3V: C4.1, C5.2, C6.2, C7.2, C8.2, C9.2, C10.2, C14.1, C15.2, C20.2, IC1.8 (VCC), J1.1 (VCC), R2.2, S1.1 (COM_1), S1.2 (COM_2), S2.1 (COM_1), S2.2 (COM_2), TP7.1, U1.1 (IOVDD), U1.10 (IOVDD), U1.22 (IOVDD), U1.33 (IOVDD), U1.42 (IOVDD), U1.43 (ADC_AVDD), U1.44 (VREG_IN), U1.48 (USB_VDD), U1.49 (IOVDD), U2.5 (VOUT)
+5V: C17.2, C18.2, C19.2, C21.1, C22.2, C23.2, C24.2, C25.2, C26.2, C27.2, C28.2, C29.2, J2.A4 (VBUS), J2.A9 (VBUS), J2.B4 (VBUS), J2.B9 (VBUS), R5.1, TP8.1, U2.1 (VIN); also elsewhere on the board
/Button_1: C11.2, R7.2, S1.3 (NO_1), S1.4 (NO_2), U1.29 (GPIO18)
/Button_2: C16.2, R6.2, S2.3 (NO_1), S2.4 (NO_2), U1.30 (GPIO19)
/Matrix_1: U1.13 (GPIO10); also elsewhere on the board
/Matrix_2: U1.14 (GPIO11); also elsewhere on the board
/QSPI_SCLK: IC1.6 (CLK), U1.52 (QSPI_SCLK)
/QSPI_SD0: IC1.5 (DI(IO0)), U1.53 (QSPI_SD0)
/QSPI_SD1: IC1.2 (DO(IO1)), U1.55 (QSPI_SD1)
/QSPI_SD2: IC1.3 (IO2), U1.54 (QSPI_SD2)
/QSPI_SD3: IC1.7 (IO3), U1.51 (QSPI_SD3)
/QSPI_SS: IC1.1 (~CS), R2.1, U1.56 (QSPI_SS)
/RUN: J1.3 (~RESET), TP1.1, U1.26 (RUN)
/SWCLK: J1.4 (SWCLK), TP4.1, U1.24 (SWCLK)
/SWD: J1.2 (SWDIO), TP5.1, U1.25 (SWD)
/USB_DM: J2.A7 (D-), J2.B7 (D-), R11.2
/USB_DP: J2.A6 (D+), J2.B6 (D+), R10.2
GND: C1.1, C2.1, C3.1, C4.2, C5.1, C6.1, C7.1, C8.1, C9.1, C10.1, C11.1, C12.2, C13.2, C14.2, C15.1, C16.1, C17.1, C18.1, C19.1, C20.1, C21.2, C22.1, C23.1, C24.1, C25.1, C26.1, C27.1, C28.1, C29.1, IC1.4 (GND), IC1.9 (EP), J1.5 (GND), J2.A1 (GND), J2.A12 (GND), J2.B1 (GND), J2.B12 (GND), J2.S1 (SHIELD), R3.2, R4.2, R6.1, R7.1, TP6.1, U1.19 (TESTEN), U1.57 (GND), U2.2 (GND), Y1.2, Y1.4; also elsewhere on the board
unnamed: C12.1, R1.1, Y1.1
unnamed: J2.A5 (CC1), R4.1
unnamed: J2.B5 (CC2), R3.1
unnamed: R8.2, R10.1
unnamed: R9.2, R11.1
unnamed: TP2.1, U1.2 (GPIO0)
unnamed: TP3.1, U1.3 (GPIO1)
unnamed: R9.1, U1.46 (USB_DM)
unnamed: R8.1, U1.47 (USB_DP)
unnamed: C1.2, C2.2, C3.2, U1.23 (DVDD), U1.45 (VREG_VOUT), U1.50 (DVDD)
unnamed: C13.1, U1.20 (XIN), Y1.3
unnamed: R1.2, U1.21 (XOUT)
unnamed: R5.2, U2.3 (EN)

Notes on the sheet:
3.3 V LDO
USB
Matrix
At best one cap per pin
One per LED Matrix Row
Power
Flash
MCU RP2040
Decoupling Caps
SWD TagConnect Header
Buttons

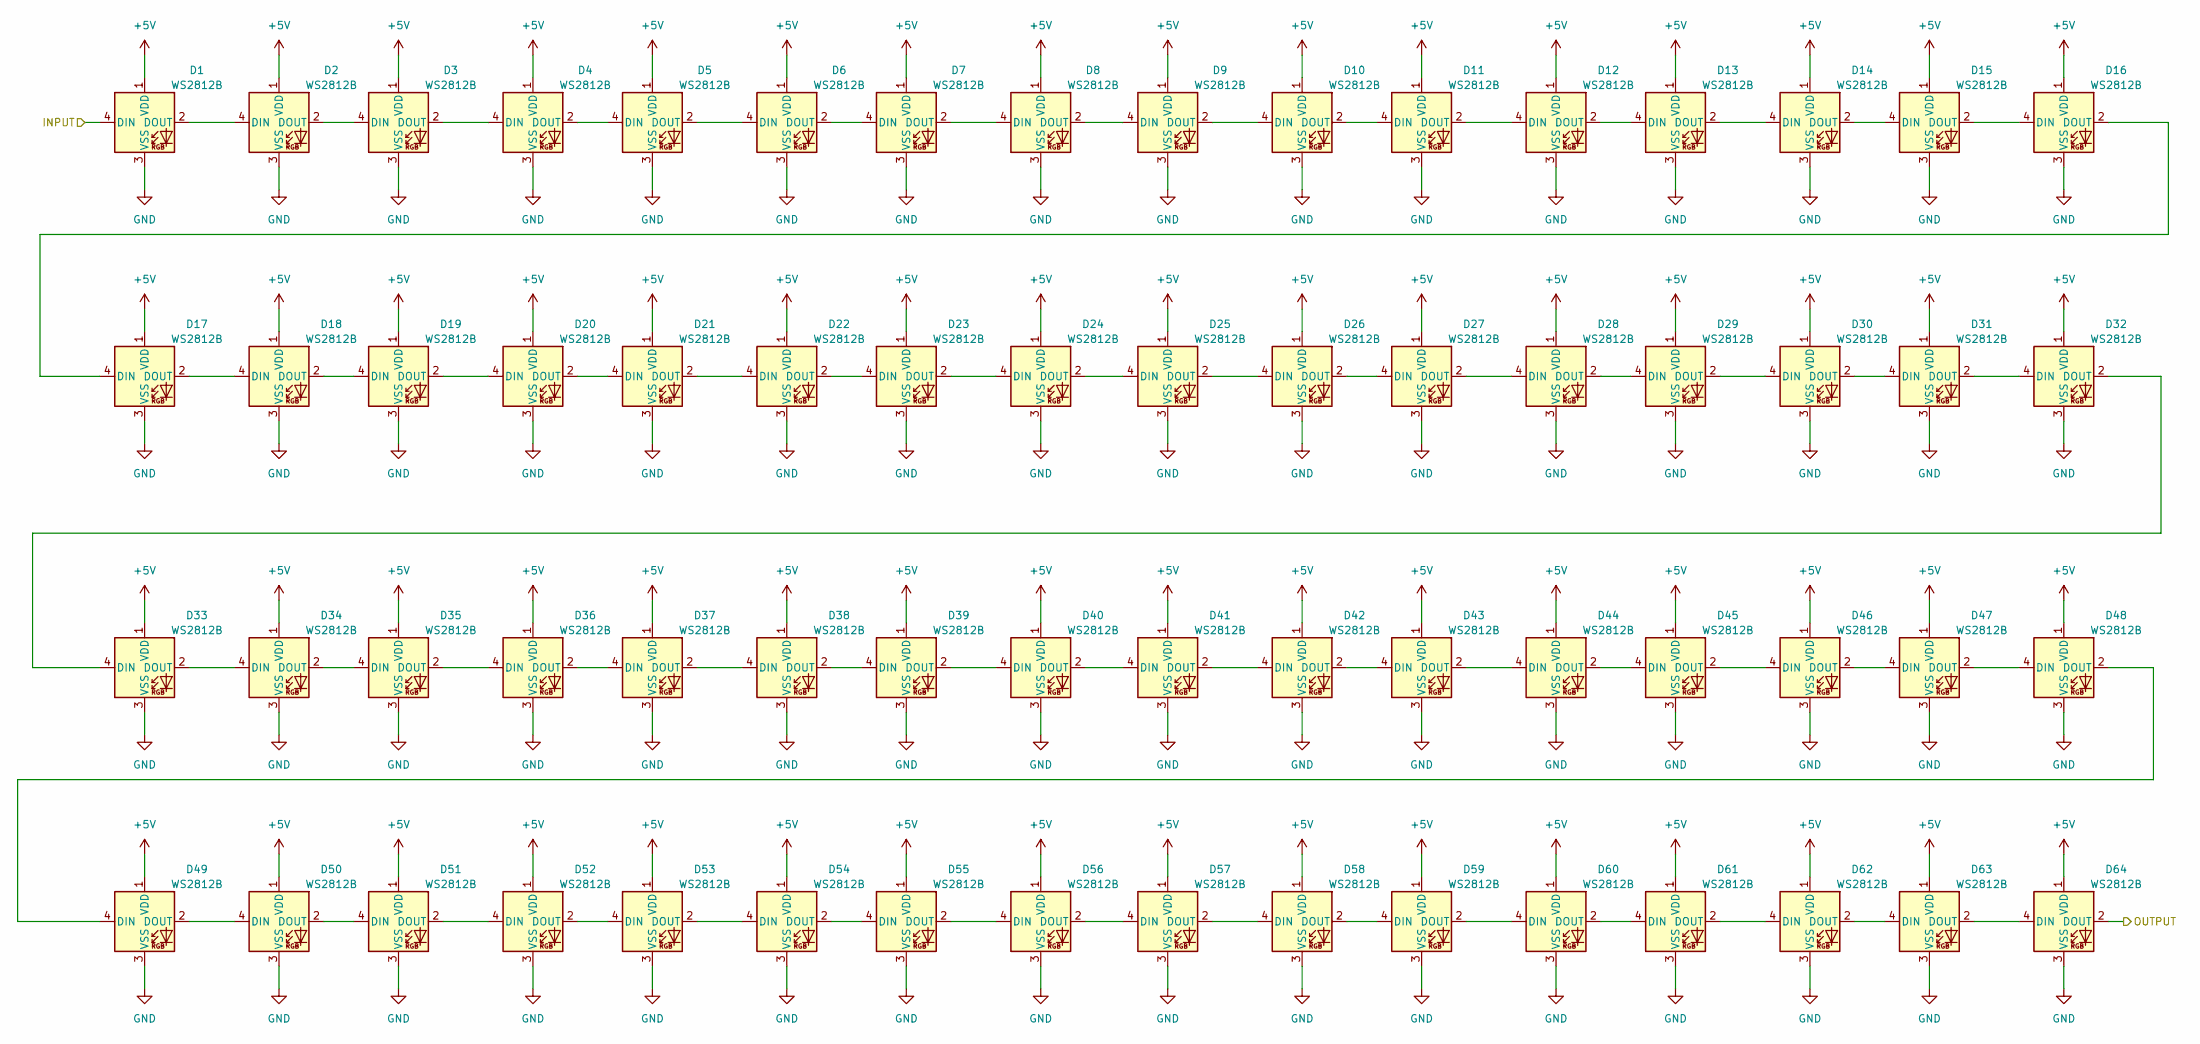
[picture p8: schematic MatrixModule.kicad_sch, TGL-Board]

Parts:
D1, D2, D3, D4, D5, D6, D7, D8, D9, D10, D11, D12, D13, D14, D15, D16, D17, D18, D19, D20, D21, D22, D23, D24, D25, D26, D27, D28, D29, D30, D31, D32, D33, D34, D35, D36, D37, D38, D39, D40, D41, D42, D43, D44, D45, D46, D47, D48, D49, D50, D51, D52, D53, D54, D55, D56, D57, D58, D59, D60, D61, D62, D63, D64: WS2812B; LED_WS2812B_XL-1615RGBC-WS2812B; LCSC C5349954

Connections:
+5V: D1.1 (VDD), D2.1 (VDD), D3.1 (VDD), D4.1 (VDD), D5.1 (VDD), D6.1 (VDD), D7.1 (VDD), D8.1 (VDD), D9.1 (VDD), D10.1 (VDD), D11.1 (VDD), D12.1 (VDD), D13.1 (VDD), D14.1 (VDD), D15.1 (VDD), D16.1 (VDD), D17.1 (VDD), D18.1 (VDD), D19.1 (VDD), D20.1 (VDD), D21.1 (VDD), D22.1 (VDD), D23.1 (VDD), D24.1 (VDD), D25.1 (VDD), D26.1 (VDD), D27.1 (VDD), D28.1 (VDD), D29.1 (VDD), D30.1 (VDD), D31.1 (VDD), D32.1 (VDD), D33.1 (VDD), D34.1 (VDD), D35.1 (VDD), D36.1 (VDD), D37.1 (VDD), D38.1 (VDD), D39.1 (VDD), D40.1 (VDD), D41.1 (VDD), D42.1 (VDD), D43.1 (VDD), D44.1 (VDD), D45.1 (VDD), D46.1 (VDD), D47.1 (VDD), D48.1 (VDD), D49.1 (VDD), D50.1 (VDD), D51.1 (VDD), D52.1 (VDD), D53.1 (VDD), D54.1 (VDD), D55.1 (VDD), D56.1 (VDD), D57.1 (VDD), D58.1 (VDD), D59.1 (VDD), D60.1 (VDD), D61.1 (VDD), D62.1 (VDD), D63.1 (VDD), D64.1 (VDD); also elsewhere on the board
/MatrixModule_1/OUTPUT: D64.2 (DOUT)
/Matrix_1: D1.4 (DIN); also elsewhere on the board
GND: D1.3 (VSS), D2.3 (VSS), D3.3 (VSS), D4.3 (VSS), D5.3 (VSS), D6.3 (VSS), D7.3 (VSS), D8.3 (VSS), D9.3 (VSS), D10.3 (VSS), D11.3 (VSS), D12.3 (VSS), D13.3 (VSS), D14.3 (VSS), D15.3 (VSS), D16.3 (VSS), D17.3 (VSS), D18.3 (VSS), D19.3 (VSS), D20.3 (VSS), D21.3 (VSS), D22.3 (VSS), D23.3 (VSS), D24.3 (VSS), D25.3 (VSS), D26.3 (VSS), D27.3 (VSS), D28.3 (VSS), D29.3 (VSS), D30.3 (VSS), D31.3 (VSS), D32.3 (VSS), D33.3 (VSS), D34.3 (VSS), D35.3 (VSS), D36.3 (VSS), D37.3 (VSS), D38.3 (VSS), D39.3 (VSS), D40.3 (VSS), D41.3 (VSS), D42.3 (VSS), D43.3 (VSS), D44.3 (VSS), D45.3 (VSS), D46.3 (VSS), D47.3 (VSS), D48.3 (VSS), D49.3 (VSS), D50.3 (VSS), D51.3 (VSS), D52.3 (VSS), D53.3 (VSS), D54.3 (VSS), D55.3 (VSS), D56.3 (VSS), D57.3 (VSS), D58.3 (VSS), D59.3 (VSS), D60.3 (VSS), D61.3 (VSS), D62.3 (VSS), D63.3 (VSS), D64.3 (VSS); also elsewhere on the board
unnamed: D1.2 (DOUT), D2.4 (DIN)
unnamed: D2.2 (DOUT), D3.4 (DIN)
unnamed: D3.2 (DOUT), D4.4 (DIN)
unnamed: D4.2 (DOUT), D5.4 (DIN)
unnamed: D5.2 (DOUT), D6.4 (DIN)
unnamed: D6.2 (DOUT), D7.4 (DIN)
unnamed: D7.2 (DOUT), D8.4 (DIN)
unnamed: D8.2 (DOUT), D9.4 (DIN)
unnamed: D9.2 (DOUT), D10.4 (DIN)
unnamed: D10.2 (DOUT), D11.4 (DIN)
unnamed: D11.2 (DOUT), D12.4 (DIN)
unnamed: D12.2 (DOUT), D13.4 (DIN)
unnamed: D13.2 (DOUT), D14.4 (DIN)
unnamed: D14.2 (DOUT), D15.4 (DIN)
unnamed: D15.2 (DOUT), D16.4 (DIN)
unnamed: D16.2 (DOUT), D17.4 (DIN)
unnamed: D17.2 (DOUT), D18.4 (DIN)
unnamed: D18.2 (DOUT), D19.4 (DIN)
unnamed: D19.2 (DOUT), D20.4 (DIN)
unnamed: D20.2 (DOUT), D21.4 (DIN)
unnamed: D21.2 (DOUT), D22.4 (DIN)
unnamed: D22.2 (DOUT), D23.4 (DIN)
unnamed: D23.2 (DOUT), D24.4 (DIN)
unnamed: D24.2 (DOUT), D25.4 (DIN)
unnamed: D25.2 (DOUT), D26.4 (DIN)
unnamed: D26.2 (DOUT), D27.4 (DIN)
unnamed: D27.2 (DOUT), D28.4 (DIN)
unnamed: D28.2 (DOUT), D29.4 (DIN)
unnamed: D29.2 (DOUT), D30.4 (DIN)
unnamed: D30.2 (DOUT), D31.4 (DIN)
unnamed: D31.2 (DOUT), D32.4 (DIN)
unnamed: D32.2 (DOUT), D33.4 (DIN)
unnamed: D33.2 (DOUT), D34.4 (DIN)
unnamed: D34.2 (DOUT), D35.4 (DIN)
unnamed: D35.2 (DOUT), D36.4 (DIN)
unnamed: D36.2 (DOUT), D37.4 (DIN)
unnamed: D37.2 (DOUT), D38.4 (DIN)
unnamed: D38.2 (DOUT), D39.4 (DIN)
unnamed: D39.2 (DOUT), D40.4 (DIN)
unnamed: D40.2 (DOUT), D41.4 (DIN)
unnamed: D41.2 (DOUT), D42.4 (DIN)
unnamed: D42.2 (DOUT), D43.4 (DIN)
unnamed: D43.2 (DOUT), D44.4 (DIN)
unnamed: D44.2 (DOUT), D45.4 (DIN)
unnamed: D45.2 (DOUT), D46.4 (DIN)
unnamed: D46.2 (DOUT), D47.4 (DIN)
unnamed: D47.2 (DOUT), D48.4 (DIN)
unnamed: D48.2 (DOUT), D49.4 (DIN)
unnamed: D49.2 (DOUT), D50.4 (DIN)
unnamed: D50.2 (DOUT), D51.4 (DIN)
unnamed: D51.2 (DOUT), D52.4 (DIN)
unnamed: D52.2 (DOUT), D53.4 (DIN)
unnamed: D53.2 (DOUT), D54.4 (DIN)
unnamed: D54.2 (DOUT), D55.4 (DIN)
unnamed: D55.2 (DOUT), D56.4 (DIN)
unnamed: D56.2 (DOUT), D57.4 (DIN)
unnamed: D57.2 (DOUT), D58.4 (DIN)
unnamed: D58.2 (DOUT), D59.4 (DIN)
unnamed: D59.2 (DOUT), D60.4 (DIN)
unnamed: D60.2 (DOUT), D61.4 (DIN)
unnamed: D61.2 (DOUT), D62.4 (DIN)
unnamed: D62.2 (DOUT), D63.4 (DIN)
unnamed: D63.2 (DOUT), D64.4 (DIN)

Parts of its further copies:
D65, D66, D67, D68, D69, D70, D71, D72, D73, D74, D75, D76, D77, D78, D79, D80, D81, D82, D83, D84, D85, D86, D87, D88, D89, D90, D91, D92, D93, D94, D95, D96, D97, D98, D99, D100, D101, D102, D103, D104, D105, D106, D107, D108, D109, D110, D111, D112, D113, D114, D115, D116, D117, D118, D119, D120, D121, D122, D123, D124, D125, D126, D127, D128: WS2812B; LED_WS2812B_XL-1615RGBC-WS2812B; LCSC C5349954

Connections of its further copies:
+5V: D65.1 (VDD), D66.1 (VDD), D67.1 (VDD), D68.1 (VDD), D69.1 (VDD), D70.1 (VDD), D71.1 (VDD), D72.1 (VDD), D73.1 (VDD), D74.1 (VDD), D75.1 (VDD), D76.1 (VDD), D77.1 (VDD), D78.1 (VDD), D79.1 (VDD), D80.1 (VDD), D81.1 (VDD), D82.1 (VDD), D83.1 (VDD), D84.1 (VDD), D85.1 (VDD), D86.1 (VDD), D87.1 (VDD), D88.1 (VDD), D89.1 (VDD), D90.1 (VDD), D91.1 (VDD), D92.1 (VDD), D93.1 (VDD), D94.1 (VDD), D95.1 (VDD), D96.1 (VDD), D97.1 (VDD), D98.1 (VDD), D99.1 (VDD), D100.1 (VDD), D101.1 (VDD), D102.1 (VDD), D103.1 (VDD), D104.1 (VDD), D105.1 (VDD), D106.1 (VDD), D107.1 (VDD), D108.1 (VDD), D109.1 (VDD), D110.1 (VDD), D111.1 (VDD), D112.1 (VDD), D113.1 (VDD), D114.1 (VDD), D115.1 (VDD), D116.1 (VDD), D117.1 (VDD), D118.1 (VDD), D119.1 (VDD), D120.1 (VDD), D121.1 (VDD), D122.1 (VDD), D123.1 (VDD), D124.1 (VDD), D125.1 (VDD), D126.1 (VDD), D127.1 (VDD), D128.1 (VDD); also elsewhere on the board
/MatrixModule_2/OUTPUT: D128.2 (DOUT)
/Matrix_2: D65.4 (DIN); also elsewhere on the board
GND: D65.3 (VSS), D66.3 (VSS), D67.3 (VSS), D68.3 (VSS), D69.3 (VSS), D70.3 (VSS), D71.3 (VSS), D72.3 (VSS), D73.3 (VSS), D74.3 (VSS), D75.3 (VSS), D76.3 (VSS), D77.3 (VSS), D78.3 (VSS), D79.3 (VSS), D80.3 (VSS), D81.3 (VSS), D82.3 (VSS), D83.3 (VSS), D84.3 (VSS), D85.3 (VSS), D86.3 (VSS), D87.3 (VSS), D88.3 (VSS), D89.3 (VSS), D90.3 (VSS), D91.3 (VSS), D92.3 (VSS), D93.3 (VSS), D94.3 (VSS), D95.3 (VSS), D96.3 (VSS), D97.3 (VSS), D98.3 (VSS), D99.3 (VSS), D100.3 (VSS), D101.3 (VSS), D102.3 (VSS), D103.3 (VSS), D104.3 (VSS), D105.3 (VSS), D106.3 (VSS), D107.3 (VSS), D108.3 (VSS), D109.3 (VSS), D110.3 (VSS), D111.3 (VSS), D112.3 (VSS), D113.3 (VSS), D114.3 (VSS), D115.3 (VSS), D116.3 (VSS), D117.3 (VSS), D118.3 (VSS), D119.3 (VSS), D120.3 (VSS), D121.3 (VSS), D122.3 (VSS), D123.3 (VSS), D124.3 (VSS), D125.3 (VSS), D126.3 (VSS), D127.3 (VSS), D128.3 (VSS); also elsewhere on the board
unnamed: D65.2 (DOUT), D66.4 (DIN)
unnamed: D66.2 (DOUT), D67.4 (DIN)
unnamed: D67.2 (DOUT), D68.4 (DIN)
unnamed: D68.2 (DOUT), D69.4 (DIN)
unnamed: D69.2 (DOUT), D70.4 (DIN)
unnamed: D70.2 (DOUT), D71.4 (DIN)
unnamed: D71.2 (DOUT), D72.4 (DIN)
unnamed: D72.2 (DOUT), D73.4 (DIN)
unnamed: D73.2 (DOUT), D74.4 (DIN)
unnamed: D74.2 (DOUT), D75.4 (DIN)
unnamed: D75.2 (DOUT), D76.4 (DIN)
unnamed: D76.2 (DOUT), D77.4 (DIN)
unnamed: D77.2 (DOUT), D78.4 (DIN)
unnamed: D78.2 (DOUT), D79.4 (DIN)
unnamed: D79.2 (DOUT), D80.4 (DIN)
unnamed: D80.2 (DOUT), D81.4 (DIN)
unnamed: D81.2 (DOUT), D82.4 (DIN)
unnamed: D82.2 (DOUT), D83.4 (DIN)
unnamed: D83.2 (DOUT), D84.4 (DIN)
unnamed: D84.2 (DOUT), D85.4 (DIN)
unnamed: D85.2 (DOUT), D86.4 (DIN)
unnamed: D86.2 (DOUT), D87.4 (DIN)
unnamed: D87.2 (DOUT), D88.4 (DIN)
unnamed: D88.2 (DOUT), D89.4 (DIN)
unnamed: D89.2 (DOUT), D90.4 (DIN)
unnamed: D90.2 (DOUT), D91.4 (DIN)
unnamed: D91.2 (DOUT), D92.4 (DIN)
unnamed: D92.2 (DOUT), D93.4 (DIN)
unnamed: D93.2 (DOUT), D94.4 (DIN)
unnamed: D94.2 (DOUT), D95.4 (DIN)
unnamed: D95.2 (DOUT), D96.4 (DIN)
unnamed: D96.2 (DOUT), D97.4 (DIN)
unnamed: D97.2 (DOUT), D98.4 (DIN)
unnamed: D98.2 (DOUT), D99.4 (DIN)
unnamed: D99.2 (DOUT), D100.4 (DIN)
unnamed: D100.2 (DOUT), D101.4 (DIN)
unnamed: D101.2 (DOUT), D102.4 (DIN)
unnamed: D102.2 (DOUT), D103.4 (DIN)
unnamed: D103.2 (DOUT), D104.4 (DIN)
unnamed: D104.2 (DOUT), D105.4 (DIN)
unnamed: D105.2 (DOUT), D106.4 (DIN)
unnamed: D106.2 (DOUT), D107.4 (DIN)
unnamed: D107.2 (DOUT), D108.4 (DIN)
unnamed: D108.2 (DOUT), D109.4 (DIN)
unnamed: D109.2 (DOUT), D110.4 (DIN)
unnamed: D110.2 (DOUT), D111.4 (DIN)
unnamed: D111.2 (DOUT), D112.4 (DIN)
unnamed: D112.2 (DOUT), D113.4 (DIN)
unnamed: D113.2 (DOUT), D114.4 (DIN)
unnamed: D114.2 (DOUT), D115.4 (DIN)
unnamed: D115.2 (DOUT), D116.4 (DIN)
unnamed: D116.2 (DOUT), D117.4 (DIN)
unnamed: D117.2 (DOUT), D118.4 (DIN)
unnamed: D118.2 (DOUT), D119.4 (DIN)
unnamed: D119.2 (DOUT), D120.4 (DIN)
unnamed: D120.2 (DOUT), D121.4 (DIN)
unnamed: D121.2 (DOUT), D122.4 (DIN)
unnamed: D122.2 (DOUT), D123.4 (DIN)
unnamed: D123.2 (DOUT), D124.4 (DIN)
unnamed: D124.2 (DOUT), D125.4 (DIN)
unnamed: D125.2 (DOUT), D126.4 (DIN)
unnamed: D126.2 (DOUT), D127.4 (DIN)
unnamed: D127.2 (DOUT), D128.4 (DIN)

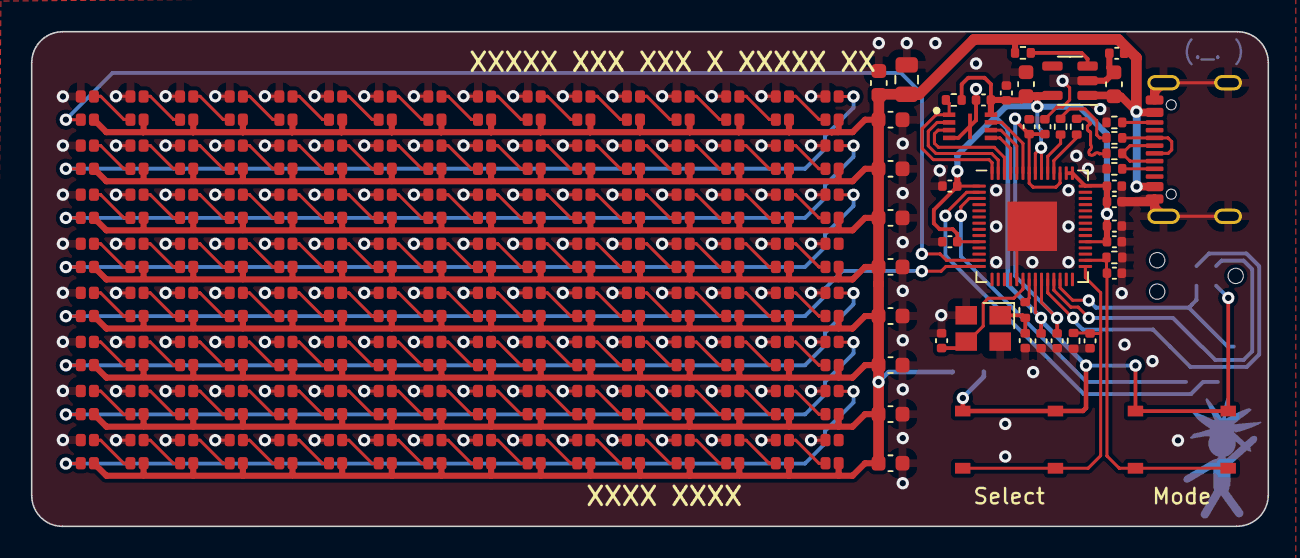
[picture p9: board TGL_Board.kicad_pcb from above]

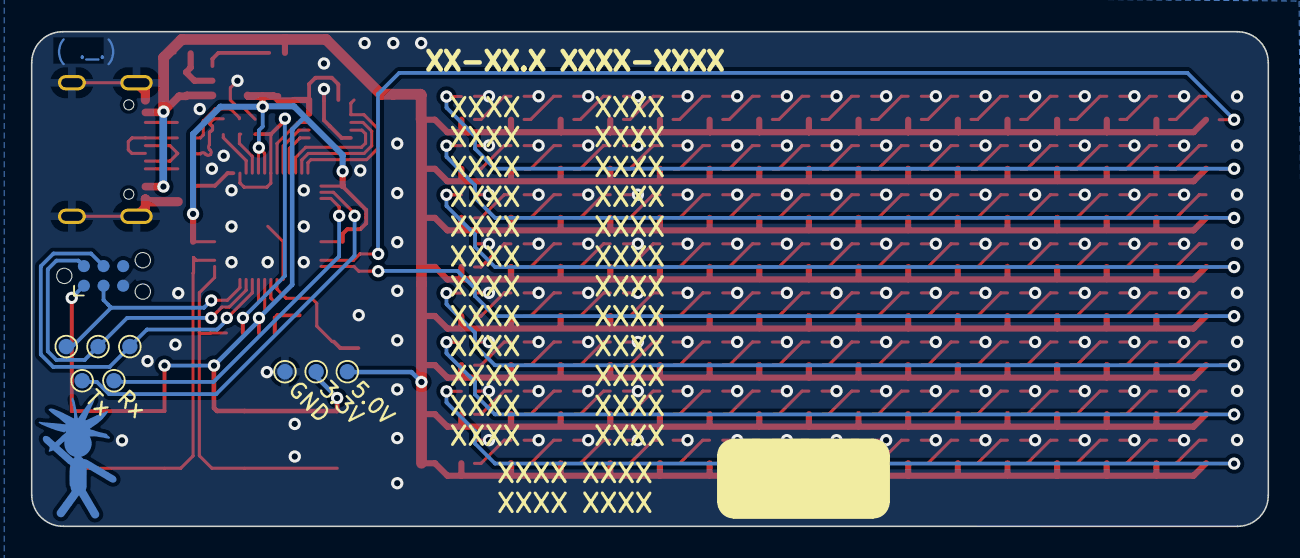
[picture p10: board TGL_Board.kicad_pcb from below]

Board: 2 copper layers, 80.0 x 32.0 mm, 184 parts (9 on the bottom side), 157 nets.

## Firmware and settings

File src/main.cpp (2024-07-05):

//
// © 2024 Leonhard Baschang
//

#ifdef ARDUINO
    #include <Arduino.h>
#else
    #include "pico/stdlib.h"
#endif

#include "hardware/watchdog.h"

#include "beo_common.h"

#include "PIOMatrixOutput/pio_matrix_output.h"

#include "FlashController/flash_controller.h"

#include "TextController/scroll_text.h"
#include "TextController//static_text.h"
#include "TextController/tiny_text.h"


#include "DinoGame/dinoGame.h"
#include "Firework/firework_animation.h"
#include "TetrisGame/tetris.h"
#include "SnakeAI/snake_ai_animation.h"
#include "GameOfLife/game_of_life_animation.h"
#include "FixedAnimation/fixed_animation.h"
#include "RainbowAnimation/rainbow_animation.h"
#include "DisplayText/display_text.h"
#include "BrightnessControl/brightness_control.h"
#include "MeteoriteAnimation/meteorite_animation.h"

#include "Menu/menu_controller.h"
#include "Menu/menu_entry.h"

#define BUTTON1 18
#define BUTTON2 19

#define WATCHDOG_RESET_TIME 30
uint32_t lastWatchdogReset = 0;


Color frame[8][16];


PIO pio = pio0;


MatrixOutput ledMatrix(pio, 0, 0, 10, 11);

FlashController flash;

ScrollText scrollText(&ledMatrix, &frame);
StaticText staticText(&ledMatrix, &frame);
TinyText tinyText(&ledMatrix, &frame);


DinoGame dinoGame(&ledMatrix, &frame, &staticText, &flash);
FireworkAnimation fireworks(&ledMatrix, &frame);
Tetris tetrisGame(&ledMatrix, &frame, &staticText, &flash);
SnakeAI snake(&ledMatrix, &frame);
GameOfLife gameOfLife(&ledMatrix, &frame);
FixedAnimation fixedAnimation(&ledMatrix, &frame);
RainbowAnimation rainbowAnimationFixed(&ledMatrix, &frame);
RainbowAnimation rainbowAnimationSmooth(&ledMatrix, &frame);
DisplayText displayText(&ledMatrix, &frame, &scrollText);
MeteoriteAnimation meteoriteAnimation(&ledMatrix, &frame);

BrightnessControl brightnessControl(&ledMatrix, &frame, &tinyText, &flash);

MenuController menuController(&staticText);
MenuEntry menuEntryAnimation;
MenuEntry menuEntryGame;
MenuEntry menuEntryText;
MenuEntry menuEntrySettings;





void button_isr(uint gpio, uint32_t events){
    uint8_t state = events>>3; // Rise: 8>>3 = 1; Fall: 4>>3 = 0
    switch (gpio){
        case BUTTON1:
            menuController.button1ISR(state);
            break;
        case BUTTON2:
            menuController.button2ISR(state);
            break;
        default:
            break;
    }
}




void setup() {

    Serial.begin(115200);



    Serial.println("TGL-Board V1.0");
    Serial.println("Leonhard Baschang 2024");




    gpio_set_irq_enabled_with_callback(BUTTON1, GPIO_IRQ_EDGE_RISE | GPIO_IRQ_EDGE_FALL, true, &button_isr);
    gpio_set_irq_enabled_with_callback(BUTTON2, GPIO_IRQ_EDGE_RISE | GPIO_IRQ_EDGE_FALL, true, &button_isr);

    // If no data is stored/Clean flash
    if(FlashController::readData(1) == nullptr){
        FlashController::eraseAllData();
        uint8_t data[] = {0,0,0,0};
        flash.writeData(1,data);
        flash.writeData(2,data);
        uint32_t value = 10;
        flash.writeData(3,(uint8_t*)&value);
    }

    // Watchdog must be reset every 100 ms.
    // Watchdog is disabled when cores are in debug mode
    watchdog_enable(100, true);




    // Brightness
    brightnessControl.setBrightnessVar(&globalBrightness);
    brightnessControl.setBrightnessFlashKey(3);
    brightnessControl.loadBrightnessFromFlash();

    // Display programs settings
    rainbowAnimationFixed.setMode(fixed);
    rainbowAnimationSmooth.setMode(smooth);

    // Matrix settings
    ledMatrix.enableSubframes();



    // Menu settings - begin
    menuEntryText.addProgram(&displayText);
    menuEntryText.setName("1.%1Text");

    menuController.addNewEntry(&menuEntryText);



    menuEntryAnimation.addProgram(&fireworks);
    menuEntryAnimation.addProgram(&snake);
    menuEntryAnimation.addProgram(&gameOfLife);
    menuEntryAnimation.addProgram(&meteoriteAnimation);
    menuEntryAnimation.addProgram(&rainbowAnimationSmooth);
    menuEntryAnimation.addProgram(&rainbowAnimationFixed);
    menuEntryAnimation.addProgram(&fixedAnimation);

    menuEntryAnimation.setName("2.%1Animations");

    menuController.addNewEntry(&menuEntryAnimation);



    menuEntryGame.addProgram(&dinoGame); // menuEntryGame.addProgram(&tetrisGame); // For tetris
    menuEntryGame.setName("3.%1Dino%2Game");// menuEntryGame.setName("3.%1Tetris"); // For tetris

    menuController.addNewEntry(&menuEntryGame);


    menuEntrySettings.addProgram(&brightnessControl);
    menuEntrySettings.setName("4.%1Set%2Brightness");

    menuController.addNewEntry(&menuEntrySettings);



    menuEntryText.restart();
    // Menu settings - end








}




void loop() {

    menuController.loop();

    if(beo::millis() - lastWatchdogReset > WATCHDOG_RESET_TIME){
        lastWatchdogReset = beo::millis();
        watchdog_update();
    }

}

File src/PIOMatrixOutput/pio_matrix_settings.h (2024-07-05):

//
// © 2024 Leonhard Baschang
//

#ifndef TGL_BOARD_PIO_MATRIX_OUTPUT_PIO_MATRIX_SETTINGS_H
#define TGL_BOARD_PIO_MATRIX_OUTPUT_PIO_MATRIX_SETTINGS_H


#define MATRIX_LENGTH 16
#define MATRIX_HEIGHT 8


#define MATRIX_SUBMATRIX_COUNT 2


#define MATRIX_SIZE (MATRIX_LENGTH*MATRIX_HEIGHT)
#define MATRIX_SUBMATRIX_SIZE (MATRIX_SIZE/MATRIX_SUBMATRIX_COUNT)


#define MAX_FRAMES_IN_BUFFER 10
#define MAX_SUBFRAMES 8 // Should/Must be a multiple of 2. 1 is also a legit value

#define TIMER_INDEX 1

#define dataSendTime (1920 + 50 + 6) // (time_to_output_data + time_to_latch_data + some_buffer_time) (in µs)
#define subframePauseIntervall (0) // Time to add after dataSendTime in µs. Only in steps of 10. +/- 5µs

#endif //TGL_BOARD_PIO_MATRIX_OUTPUT_PIO_MATRIX_SETTINGS_H

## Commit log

2024-04-23 Huge update (Frame Buffer, Subframes, ScrollText, ...)
2024-04-29 Added static frame -> Less RAM usage
2024-04-30 Fixed bug in firework
    [FireworkAnimation.h]
2024-05-06 fixed bug in framebuffer.cpp
2024-05-08 Added pcb files
    [MatrixModule.kicad_sch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]
2024-05-09 use already existing frame instead of creating own
2024-05-14 Modified tetris to work with new static text controller. Fixed bug in static text controller
    [main.cpp]
2024-05-17 Added tiny text controller and reworked all text controllers
    [main.cpp]
2024-05-18 Removed arduino specific code and added support for Pico C-SDK
2024-05-19 fixed some timing issues
    [pio_matrix_settings.h]
2024-05-26 Added switcher menu
2024-05-27 Set Platform IO framework version
2024-05-27 Text now switches on falling edge
2024-06-14 Added watchdog timer
2024-06-26 New board_text_config.h
2024-07-02 beo millis
2024-07-04 more and better README
    [TGL-Board_BOM.csv, TGL-Board_Stand.3mf, TGL-Board_Stand.stl]
2024-07-04 Fixed flash controller and some typos
    [main.cpp]
2024-07-04 last minute bug fixing ( ._.)
    [main.cpp]
